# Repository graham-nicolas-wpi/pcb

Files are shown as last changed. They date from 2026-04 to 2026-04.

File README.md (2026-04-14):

# Modular NeoPixel Smart Clock

This repository contains the full clock project for a custom four-digit NeoPixel display board and its long-term two-MCU software stack.

## Permanent Hardware Direction

The custom PCB stays physically unchanged.

- Arduino Leonardo remains on the board as the permanent renderer and board-native hardware controller
- ESP32-WROOM-32E is the external high-level host platform
- ESP32 talks to Leonardo over exposed header pins only
- ESP32 does not directly drive `LED_DIN`
- no PCB redesign and no soldering to hidden custom-board traces are part of the main plan

Preferred UART link:

- ESP32 `GPIO17 TX` -> Leonardo `D0 / RX`
- Leonardo `D1 / TX` -> ESP32 `GPIO16 RX` through a divider or level shifter
- common `GND`

## Repo Layout

- `hardware/pcb/` - KiCad sources, fabrication outputs, schematic exports
- `firmware/arduino/clock_firmware/` - Leonardo renderer runtime using the `ClockRender/1` protocol
- `firmware/arduino/clock_calibration_firmware/` - Leonardo calibration and map-writing firmware using `ClockCal/1`
- `firmware/platformio/esp32_clock/` - ESP32 host platform with web UI, storage, time/network logic, and renderer link control
- `softwear/clockWinder_gui/` - desktop serial tools for Leonardo runtime and calibration workflows
- `docs/leonardo-renderer-esp32-host.md` - canonical coprocessor architecture and serial/render contract

## MCU Responsibilities

### Leonardo

The Leonardo is the stable board appliance:

- renders digits, colon, and decimal to the onboard NeoPixels
- keeps LED mapping and physical calibration authoritative on-board
- reads board buttons and RTC
- exposes a compact serial contract
- supports local fallback clock/timer/stopwatch behavior when no host is attached

### ESP32

The ESP32 is the product brain:

- owns presets, faces, widgets, schedules, and runtime config
- owns NTP, Wi-Fi, storage, browser UI, and future integrations
- compiles rich features into stable renderer commands or `FRAME24` payloads
- treats the Leonardo as a renderer coprocessor instead of replacing it

## Recommended Reading

- Firmware overview: [firmware/README.md](firmware/README.md)
- Leonardo/ESP32 contract: [docs/leonardo-renderer-esp32-host.md](docs/leonardo-renderer-esp32-host.md)
- ESP32 host overview: [firmware/platformio/esp32_clock/README.md](firmware/platformio/esp32_clock/README.md)
- ESP32 host architecture: [firmware/platformio/esp32_clock/ARCHITECTURE.md](firmware/platformio/esp32_clock/ARCHITECTURE.md)
- Desktop GUI notes: [softwear/clockWinder_gui/README.md](softwear/clockWinder_gui/README.md)

## Recommended Workflow

### Bring up the board renderer

1. Flash `firmware/arduino/clock_firmware/` to the Leonardo for normal operation
2. Flash `firmware/arduino/clock_calibration_firmware/` only when you need to remap LEDs
3. Use the desktop GUI for direct Leonardo control or calibration

### Build the long-term product platform

1. Work in `firmware/platformio/esp32_clock/`
2. Connect the ESP32 to the Leonardo over the header UART link
3. Add new features on the ESP32 and emit `ClockRender/1` commands or `FRAME24` frames

## Project Status

- The Leonardo runtime is now being stabilized as a durable renderer/runtime coprocessor.
- The ESP32 project is the long-term expansion surface for nearly all new features.
- The calibration workflow remains Leonardo-owned so physical board mapping stays tied to the actual renderer MCU.

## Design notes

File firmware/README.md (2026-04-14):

# Firmware Overview

This repo now has one permanent two-MCU product architecture:

- Leonardo on the custom PCB as the renderer/runtime coprocessor
- ESP32 as the external host platform over header-accessible UART

## Leonardo Firmware

Folders:

- `arduino/clock_firmware/` - normal renderer runtime using `ClockRender/1`
- `arduino/clock_calibration_firmware/` - calibration and map-writing firmware using `ClockCal/1`

Leonardo responsibilities:

- render the 31 logical targets on the onboard WS2812 chain
- keep physical mapping and calibration board-native
- read the board buttons on `D8`, `D9`, `D10`
- read the DS3231 over I2C
- support stable runtime commands and `FRAME24` rendering
- provide a useful local fallback mode when the ESP32 host is absent

Why runtime and calibration remain split:

- ATmega32U4 flash is tight
- calibration tools are still important, but they do not belong in every everyday runtime build
- keeping calibration separate makes the normal runtime leaner and more durable

## ESP32 Firmware

Folder:

- `platformio/esp32_clock/`

ESP32 responsibilities:

- own saved presets, faces, widgets, and schedules
- own LittleFS config and browser-based UX
- own NTP, network policy, and future integrations
- own command generation toward the Leonardo renderer
- compile high-level host features into stable renderer commands or `FRAME24`

The active ESP32 path no longer assumes direct control of the NeoPixel chain, button wiring, or RTC wiring on the custom board.

## Wiring Contract

Preferred host link:

- ESP32 `GPIO17 TX` -> Leonardo `D0 / RX`
- Leonardo `D1 / TX` -> ESP32 `GPIO16 RX` through level protection
- common `GND`

This architecture avoids PCB redesign and avoids soldering to hidden custom-board traces.

## Desktop App Relationship

The desktop app in `../softwear/clockWinder_gui/` still matters for:

- direct Leonardo runtime control
- calibration using the separate calibration sketch
- bench testing and development

The long-term primary UX for product features is the ESP32 web/API stack.

## What To Use

### Board bring-up

Use Leonardo runtime plus the calibration sketch.

### Product feature work

Use the ESP32 PlatformIO project and treat the Leonardo as a renderer coprocessor.

## Reference

- canonical architecture and protocol: [../docs/leonardo-renderer-esp32-host.md](../docs/leonardo-renderer-esp32-host.md)

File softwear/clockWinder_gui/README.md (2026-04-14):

# ClockWinder Desktop GUI

This is the PySide6 desktop serial tool for the clock project.

Entry point:

- `main.py`

Main package:

- `clock_gui/`

## What it does

The GUI is the desktop-side console for Leonardo runtime and calibration workflows. It supports:

- serial connection with `pyserial`
- `ClockRender/1` runtime hello/status/info
- calibration mode workflow
- mapping table editing
- JSON and header export
- runtime mode control
- brightness and colon brightness control
- color control for clock, timer, and stopwatch targets
- RTC read/set
- timer and stopwatch controls

## Package layout

- `clock_gui/app.py` - Qt application setup and styling
- `clock_gui/protocol.py` - line-based serial command helpers and response parsing
- `clock_gui/model.py` - local mapping and device state models
- `clock_gui/serial_worker.py` - worker-thread serial I/O
- `clock_gui/exports.py` - JSON/header export helpers
- `clock_gui/constants.py` - shared logical IDs, modes, presets, and UI constants
- `clock_gui/widgets/` - reusable widgets
- `clock_gui/windows/main_window.py` - main application window

## Run

Install:

```bash
pip install PySide6 pyserial
```

Launch:

```bash
python main.py
```

## Position In The Project

This app is still very relevant for the Leonardo firmware path.

For the long-term ESP32 path, the plan is different:

- the ESP32 serves its own browser UI
- the ESP32 becomes the main high-level configuration surface
- the Leonardo remains the board-native renderer under that host
- the desktop GUI becomes optional rather than mandatory

That means this app should stay clean and usable, but it does not need to become the long-term primary UX if the ESP32 web path takes over.

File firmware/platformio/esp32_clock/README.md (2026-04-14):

# ESP32 Clock Host

This PlatformIO project is the authoritative high-level host for the clock system. It does not directly drive the custom PCB LED chain.

## Host Role

The ESP32 owns:

- presets, faces, widgets, and future feature composition
- LittleFS-backed configuration and saved state
- Wi-Fi AP/STA behavior
- browser UI and HTTP API
- NTP and other future time sources
- UART communication with the Leonardo renderer

The ESP32 does not own:

- board NeoPixel `DIN`
- board button wiring
- the authoritative LED calibration map
- the board-native RTC wiring path

Those remain Leonardo responsibilities on this board revision.

## Wiring

Preferred renderer link:

- ESP32 `GPIO17 TX` -> Leonardo `D0 / RX`
- Leonardo `D1 / TX` -> ESP32 `GPIO16 RX` through a divider or level shifter
- common `GND`

This is the intended no-PCB-redesign and no-hidden-trace-solder path.

## Project Layout

- `src/main.cpp` - host startup and main loop
- `src/model/ClockConfig.h` - persisted host config model
- `src/storage/SettingsStore.*` - LittleFS JSON persistence
- `src/render/SegmentFrame.*` - stable logical-target frame model
- `src/render/FrameCompiler.*` - compiles presets/faces/widgets into a renderer frame
- `src/host/LeonardoClient.*` - UART client for `ClockRender/1`
- `src/runtime/HostRuntime.*` - host-owned timer, stopwatch, time source, and renderer orchestration
- `src/web/WebUiServer.*` - HTTP API and static file serving
- `data/*` - browser UI assets uploaded to LittleFS

## Renderer Contract

The ESP32 speaks to the Leonardo runtime using `ClockRender/1`.

Important commands include:

- `HELLO ClockRender/1`
- `STATUS?`
- `CONTROL HOST`
- `BTNREPORT 1`
- `RTC READ`
- `RTC SET ...`
- `MAP?`
- `TEST DIGITS|SEGMENTS|ALL`
- `FRAME24 <186 hex chars>`

For the full contract, see [../../../docs/leonardo-renderer-esp32-host.md](../../../docs/leonardo-renderer-esp32-host.md).

## Why This Split Matters

Future product features should usually land in one of these ESP32 layers:

- config model
- web/API surface
- storage and scheduling
- frame compiler
- renderer client/orchestration

The Leonardo should usually stay unchanged unless the stable renderer contract truly needs a new primitive.

## Upload Workflow

1. Install PlatformIO.
2. Build and upload firmware:
   - `pio run -t upload`
3. Upload web assets:
   - `pio run -t uploadfs`
4. Open serial monitor if needed:
   - `pio device monitor`

## First Boot

Default AP:

- SSID: `NeoPixelClock`
- Password: `clockclock`

Open:

- `http://192.168.4.1/`

The web UI edits host config and renderer-link settings, then drives the Leonardo renderer over UART.

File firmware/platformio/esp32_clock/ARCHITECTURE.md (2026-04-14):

# ESP32 Host Architecture

This project is the high-level host half of a two-MCU system.

## Core Idea

The ESP32 owns the evolving product model. The Leonardo owns the stable board-rendering contract.

New product features should normally be added by:

1. extending host config and storage
2. exposing the feature in the web/API layer
3. compiling the result into a stable render frame or compact renderer command

That keeps the Leonardo simple while letting the ESP32 change freely.

## Active Layers

### `src/model`

- `src/model/ClockConfig.h`

This is the host-side persisted product model. The public config now centers on:

- `network`
- `rendererLink`
- `time`
- `runtime`
- `presets`
- `widgets`
- `faces`

Legacy direct-drive hardware and mapping fields remain only for backward config compatibility and are no longer the primary model.

### `src/storage`

- `src/storage/SettingsStore.*`

Persists the host model to LittleFS and performs config import/export.

### `src/render`

- `src/render/SegmentFrame.*`
- `src/render/FrameCompiler.*`

This layer is the stability boundary.

- `SegmentFrame` is the compact logical-target render model
- `FrameCompiler` turns high-level presets, faces, widgets, and runtime state into that frame

Because the ESP32 compiles to this intermediate form, future features can grow without teaching the Leonardo what each feature means.

### `src/host`

- `src/host/LeonardoClient.*`

This is the UART transport/client for `ClockRender/1`.

Responsibilities:

- hello/status/capability probing
- renderer RTC and map reads
- host/local control negotiation
- async event handling
- `FRAME24` transport

### `src/runtime`

- `src/runtime/HostRuntime.*`

This is the orchestration layer for the host platform.

Responsibilities:

- host-owned timer and stopwatch behavior
- time-source priority `NTP -> renderer RTC -> fallback`
- periodic RTC sync back to the renderer
- renderer health polling and control refresh
- button event interpretation
- render scheduling and frame submission

### `src/web`

- `src/web/WebUiServer.*`

Thin HTTP/API layer over the host runtime and config store.

### `data`

- `data/index.html`
- `data/app.css`
- `data/app.js`

The browser UI edits host config and renderer-link settings, shows renderer health, and triggers service actions. It is no longer a mapping editor for the custom board.

## Control Flow

1. ESP32 boots and loads host config from LittleFS.
2. `LeonardoClient` opens UART2 using the configured renderer link.
3. `HostRuntime` discovers the renderer and requests host control.
4. Host state is compiled into a `SegmentFrame`.
5. The frame is sent as `FRAME24`.
6. Leonardo renders the frame using its own logical-to-physical LED map.

## Calibration Boundary

Calibration is intentionally outside the normal ESP32 host flow.

- physical mapping edits belong to the Leonardo calibration sketch
- the ESP32 host may query and export the renderer map
- the ESP32 host should not become the primary writer of board calibration data

## Design Rules

- do not reintroduce direct LED driving on the ESP32 primary path
- keep web actions thin and runtime-driven
- treat `SegmentFrame` and `ClockRender/1` as the stable renderer contract
- keep feature growth on the host side whenever possible

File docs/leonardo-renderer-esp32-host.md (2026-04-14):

# Leonardo Renderer + ESP32 Host

This document is the canonical architecture and protocol contract for the long-term no-PCB-redesign clock stack.

## Hardware Plan

The current custom PCB remains unchanged.

- Leonardo stays permanently installed on the custom board
- Leonardo keeps ownership of the onboard NeoPixel data path, board buttons, and DS3231 path
- ESP32-WROOM-32E is an external host connected through exposed headers only
- the main plan does not involve rewiring `LED_DIN`, soldering to hidden traces, or replacing the Leonardo on this board revision

Recommended UART wiring:

- ESP32 `GPIO17 TX` -> Leonardo `D0 / RX`
- Leonardo `D1 / TX` -> ESP32 `GPIO16 RX` through level protection
- common `GND`
- share power through the accessible headers as appropriate for the build

## Role Split

### Leonardo Renderer

The Leonardo is the board-native rendering appliance.

- renders logical digits, colon, and decimal
- preserves the physical LED map abstraction
- stores and uses the authoritative calibration map
- reads board buttons and RTC
- offers a stable serial control surface
- falls back to local clock/timer/stopwatch behavior when the host is absent or released

### ESP32 Host

The ESP32 is the flexible system brain.

- owns presets, faces, widgets, schedules, storage, and network policy
- owns NTP and other future time sources
- serves the browser UI and HTTP API
- compiles high-level product features into stable renderer commands
- should absorb most future feature growth without requiring Leonardo firmware changes

## Protocol Families

- `ClockRender/1` - Leonardo runtime protocol
- `ClockCal/1` - Leonardo calibration firmware protocol
- `Clock/1` - legacy runtime hello alias kept for migration compatibility

`ClockCal/1` belongs to the calibration sketch only. The normal Leonardo runtime is canonical on `ClockRender/1`.

## Transport

- UART
- `115200` baud by default
- `8N1`
- newline-delimited ASCII commands

## Runtime Control Model

The renderer has two control states:

- `CONTROL LOCAL` - Leonardo standalone behavior is active
- `CONTROL HOST` - ESP32 host is authoritative

In host mode:

- Leonardo buttons no longer mutate renderer state locally
- button presses are surfaced as events when `BTNREPORT 1` is enabled
- the ESP32 translates those events into product behavior

If host traffic stops for roughly 5 seconds, Leonardo returns to local control and emits `EV HOST TIMEOUT`.

## Core Commands

### Session and discovery

- `HELLO`
- `HELLO ClockRender/1`
- `HELLO Clock/1`
- `INFO?`
- `CAPS?`
- `STATUS?`
- `PING`

### Control and board services

- `CONTROL HOST`
- `CONTROL LOCAL`
- `BTNREPORT 0|1`
- `RTC READ`
- `RTC SET yyyy mm dd hh mm ss`
- `MAP?`
- `VALIDATE?`
- `TEST DIGITS`
- `TEST SEGMENTS`
- `TEST ALL`

### Convenience renderer commands

- `MODE CLOCK|CLOCK_SECONDS|TIMER|STOPWATCH|COLOR_DEMO`
- `BRIGHTNESS n`
- `COLONBRIGHTNESS n`
- `COLOR <target> r g b`
- `TIMER SET seconds`
- `TIMER START`
- `TIMER STOP`
- `TIMER RESET`
- `STOPWATCH START`
- `STOPWATCH STOP`
- `STOPWATCH RESET`

These are useful stable controls, but the long-term extensibility lane is the frame contract below.

## Stable Frame Contract

`FRAME24 <payload>`

- payload length: `186` hex characters
- content: `31` logical targets, each encoded as `RRGGBB`
- target order: `LogicalIds.h` order on the Leonardo runtime
- semantic level: logical display targets, not physical pixel indices

That means the ESP32 can invent richer faces, widgets, themes, schedules, and integrations, then reduce them to a `SegmentFrame` without teaching the Leonardo what each new feature means.

## Events

The Leonardo runtime may emit asynchronous events:

- `EV BUTTON BTN1 SHORT`
- `EV BUTTON BTN2 SHORT`
- `EV BUTTON BTN3 SHORT`
- `EV TIMER DONE`
- `EV HOST TIMEOUT`

## Calibration Boundary

Calibration stays Leonardo-owned.

- use `firmware/arduino/clock_calibration_firmware/` to write or repair the LED map
- use `ClockCal/1` for the calibration workflow
- the normal renderer runtime may report mapping and validation state, but it is not the primary map-editing tool

## How To Add Future Features

For most new ideas:

1. add config, storage, UI, and behavior on the ESP32
2. compile that behavior into convenience commands or `FRAME24`
3. keep the Leonardo unchanged unless the stable rendering contract truly needs a new primitive

This keeps the Leonardo durable and lets the ESP32 architecture evolve freely.

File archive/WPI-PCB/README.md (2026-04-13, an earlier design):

# Essentials of PCB Design

[][cc-by-sa]

Project-oriented PCB design course taught at WPI. The course is a evening lecture series where students learn to layout and route an embedded system. Students then receive their boards and assemble them. The class was created by [Daniel Gorbunov](https://github.com/dgorbunov) and [Hubert Liu](https://github.com/124274sashimi) in 2024 and has been run every year since through the [IEEE WPI Student Branch](https://ieee.wpi.edu), which helps fund the class. You can reach us at [gr-pcb@wpi.edu](mailto:gr-pcb@wpi.edu) if you have questions.

### Lectures
| #  | Lecture				 |
| -- |--- 				 |
| 01 | PCB Basics 		 |
| 02 | Project Design |
| 03 | Layout + Routing |
| 04 | Working with KiCad |

### Materials
| Folder 	  | Contents		 |
| -- 	  | --- 			 |
| `datasheets` | Datasheets for major parts  |
| `sample_board`  | Sample board design |
| `slides` | PDFs of slides	 	|
| `starter_board` | Starter template design | 
| `code` | Code examples	 |

### Lecture Recordings

> Note: To access the lecture recordings, you must sign in with a WPI account. This is WPI's policy for Echo360 recordings.

| Year  | Term  | Echo360 |
| ----- | ----- | --- |
| 2024 | A-Term | [Link](https://echo360.org/collection/4c2d5caf-a301-4c32-a2dd-bdd8c8c0b9d9/public) | 
| 2025 | A-Term | [Link](https://echo360.org/collection/bc2acf2f-69f2-4496-9638-cb1b12c30087/public) |
| 2026 | C-Term | [Link](https://echo360.org/collection/0ecf9c61-5003-4061-9b4f-ee87c14e6741/public) |

## Getting Started
Not sure where to get started on your design? You'll need to download and install [KiCad](https://www.kicad.org/download/). You'll also need the [Arduino IDE](https://www.arduino.cc/en/software) to program your board.

### Board
To get started on your own board design, navigate to [starter_board](https://github.com/IEEE-WPI/pcb/tree/main/starter_board) and read the instructions in the `README` file.

### Code
To get started uploading code to your board, navigate to [code](https://github.com/IEEE-WPI/pcb/tree/main/code) and read the instructions in the `README` file.

## License
This work is licensed under a
[Creative Commons Attribution-ShareAlike 4.0 International License][cc-by-sa].

[][cc-by-sa]

[cc-by-sa]: http://creativecommons.org/licenses/by-sa/4.0/
[cc-by-sa-image]: https://licensebuttons.net/l/by-sa/4.0/88x31.png
[cc-by-sa-shield]: https://img.shields.io/badge/License-CC%20BY--SA%204.0-lightgrey.svg

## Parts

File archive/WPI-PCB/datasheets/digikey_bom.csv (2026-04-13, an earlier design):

Country of Origin may be different at time of shipment.
Index | Manufacturer Part Number | Manufacturer Name | Description | Availability | Stock Status | Requested Quantity 1 | Pack Quantity 1 | Pack Type 1 | Digi-Key Part Number 1 | Unit Price 1 | Extended Price 1 | Minimum Order Quantity 1 | Requested Part Number | Lead Weeks | Datasheet | US Import Tariff | Note | Part Status | RoHS Status | Moisture Sensitivity Level (MSL) | ECCN | HTSUS | Country of Origin | Environmental Information | Original Part numbers
1 | ATMEGA32U4-AU | Microchip Technology | IC MCU 8BIT 32KB FLASH 44TQFP | 14,657 | In Stock | 1 | 1 | Tray | ATMEGA32U4-AU-ND | 5.29000 | $5.29 | 1 | atmega32u4-au | 4 | http://ww1.microchip.com/downloads/en/DeviceDoc/Atmel-7766-8-bit-AVR-ATmega16U4-32U4_Summary.pdf | - |  | Active | ROHS3 Compliant | 3 (168 Hours) | EAR99 | 8542.31.0015 | Thailand | https://ww1.microchip.com/downloads/aemDocuments/documents/corporate-responsibilty/environmental/product-regulatory-information/Semiconductor_EnvCoC.pdf|https://ww1.microchip.com/downloads/aemDocuments/documents/corporate-responsibilty/environmental/product-regulatory-information/Microchip_REACH_Statement.pdf | atmega32u4-au
2 | 865080142007 | Würth Elektronik | CAP ALUM 100UF 20% 6.3V SMD | 2,805 | In Stock | 1 | 1 | Cut Tape (CT) | 732-8472-1-ND | 0.20000 | $0.20 | 1 | 732-8472-1-ND | 26 | https://www.we-online.com/components/products/datasheet/865080142007.pdf | May apply on shipments to the U.S. |  | Active | ROHS3 Compliant | 1 (Unlimited) | EAR99 | 8532.22.0020 | China | https://mm.digikey.com/Volume0/opasdata/d220001/medias/docus/744/Certificate_of_Compliance_ROHS.pdf | 732-8472-1-ND
3 | CL21B105KPFNNNE | Samsung Electro-Mechanics | CAP CER 1UF 10V X7R 0805 | 763,033 | In Stock | 2 | 2 | Cut Tape (CT) | 1276-1275-1-ND | 0.10000 | $0.20 | 1 | 1276-1275-1-ND | 22 | http://www.samsungsem.com/kr/support/product-search/mlcc/CL21B105KPFNNNE.jsp | - |  | Active | ROHS3 Compliant | 1 (Unlimited) | EAR99 | 8532.24.0020 | Philippines | https://www.samsungsem.com/files/fileDown.do?key=ed1dfdfa-645e-4252-b707-17f9b1502dd1|https://www.samsungsem.com/global/support/certificate/product-stewardship.do | 1276-1275-1-ND
4 | CL21C220JBANFNC | Samsung Electro-Mechanics | CAP CER 22PF 50V C0G/NP0 0805 | 150,218 | In Stock | 2 | 2 | Cut Tape (CT) | 1276-2606-1-ND | 0.10000 | $0.20 | 1 | 1276-2606-1-ND | 22 | http://www.samsungsem.com/kr/support/product-search/mlcc/CL21C220JBANFNC.jsp | - |  | Active | ROHS3 Compliant | 1 (Unlimited) | EAR99 | 8532.24.0020 | China | https://www.samsungsem.com/files/fileDown.do?key=ed1dfdfa-645e-4252-b707-17f9b1502dd1|https://www.samsungsem.com/global/support/certificate/product-stewardship.do | 1276-2606-1-ND
5 | CL21B104KBCNNNC | Samsung Electro-Mechanics | CAP CER 0.1UF 50V X7R 0805 | 1,739,088 | In Stock | 1 | 1 | Cut Tape (CT) | 1276-1003-1-ND | 0.10000 | $0.10 | 1 | 1276-1003-1-ND | 22 | https://mm.digikey.com/Volume0/opasdata/d220001/medias/docus/609/CL21B104KBCNNN_Spec.pdf | - |  | Active | ROHS3 Compliant | 1 (Unlimited) | EAR99 | 8532.24.0020 | Philippines | https://www.samsungsem.com/files/fileDown.do?key=ed1dfdfa-645e-4252-b707-17f9b1502dd1|https://www.samsungsem.com/global/support/certificate/product-stewardship.do | 1276-1003-1-ND
6 | USB3076-30-A | GCT | MICRO B SKT, BOTTOM-SMT, R/A, 30 | 45,985 | In Stock | 1 | 1 | Cut Tape (CT) | 2073-USB3076-30-ACT-ND | 0.70000 | $0.70 | 1 | 2073-USB3076-30-ACT-ND | 9 | https://gct.co/files/specs/usb3076-spec.pdf | May apply on shipments to the U.S. |  | Active | ROHS3 Compliant | Not Applicable | EAR99 | 8536.69.4040 | China | https://gct.co/files/info/gct_certificate_of_compliance.pdf | 2073-USB3076-30-ACT-ND
7 | LNCD1-16M | NDK America, Inc. | CRYSTAL 16.0000MHZ 8PF SMD | 31,951 | In Stock | 1 | 1 | Cut Tape (CT) | 644-LNCD1-16MCT-ND | 0.58000 | $0.58 | 1 | 644-LNCD1-16MCT-ND | 15 | https://mm.digikey.com/Volume0/opasdata/d220001/medias/docus/973/NX5032GA.pdf | - |  | Active | RoHS Compliant | 1 (Unlimited) | EAR99 | 8541.60.0050 | China |  | 644-LNCD1-16MCT-ND
8 | B1701TW--20P000314U1930 | Harvatek Corporation | LED WHITE 0805 SMD | 31,804 | In Stock | 2 | 2 | Cut Tape (CT) | 3147-B1701TW--20P000314U1930CT-ND | 0.10000 | $0.20 | 1 | 3147-B1701TW--20P000314U1930CT-ND | 8 | https://mm.digikey.com/Volume0/opasdata/d220001/medias/docus/3791/B1701TW--20P000314U1930.pdf | - |  | Active | RoHS Compliant | 2A (4 Weeks) | EAR99 | 8541.41.0000 | Taiwan | https://mm.digikey.com/Volume0/opasdata/d220001/medias/docus/6223/Harvatek%20Corp%20REACH%20235%20Jun%202023%20Statement.pdf | 3147-B1701TW--20P000314U1930CT-ND
9 | PH1-20-UA | Adam Tech | CONN HEADER VERT 20POS 2.54MM | 8,135 | In Stock | 1 | 1 | Bag | 2057-PH1-20-UA-ND | 0.36000 | $0.36 | 1 | 2057-PH1-20-UA-ND | 14 | https://app.adam-tech.com/products/download/data_sheet/201605/ph1-xx-ua-data-sheet.pdf | May apply on shipments to the U.S. |  | Active | ROHS3 Compliant | 1 (Unlimited) | EAR99 | 8536.69.4040 | China |  | 2057-PH1-20-UA-ND
10 | PH2-06-UA | Adam Tech | CONN HEADER VERT 6POS 2.54MM | 11,624 | In Stock | 1 | 1 | Bag | 2057-PH2-06-UA-ND | 0.12000 | $0.12 | 1 | 2057-PH2-06-UA-ND | 14 | https://app.adam-tech.com/products/download/data_sheet/202065/ph2-xx-ua-data-sheet.pdf | May apply on shipments to the U.S. |  | Active | ROHS3 Compliant | 1 (Unlimited) | EAR99 | 8536.69.4040 | China |  | 2057-PH2-06-UA-ND
11 | RC0805FR-07100RL | YAGEO | RES 100 OHM 1% 1/8W 0805 | 169,983 | In Stock | 2 | 2 | Cut Tape (CT) | 311-100CRCT-ND | 0.10000 | $0.20 | 1 | 311-100CRCT-ND | 18 | https://www.yageo.com/upload/media/product/products/datasheet/rchip/PYu-RC_Group_51_RoHS_L_12.pdf | May apply on shipments to the U.S. |  | Active | ROHS3 Compliant | 1 (Unlimited) | EAR99 | 8533.21.0030 | Taiwan | https://www.yageo.com/en/Download/Index/certificates#rchip | 311-100CRCT-ND
12 | RC0805FR-0722RL | YAGEO | RES 22 OHM 1% 1/8W 0805 | 499,387 | In Stock | 2 | 2 | Cut Tape (CT) | 311-22.0CRCT-ND | 0.10000 | $0.20 | 1 | 311-22.0CRCT-ND | 18 | https://www.yageo.com/upload/media/product/products/datasheet/rchip/PYu-RC_Group_51_RoHS_L_12.pdf | May apply on shipments to the U.S. |  | Active | ROHS3 Compliant | 1 (Unlimited) | EAR99 | 8533.21.0030 | Taiwan | https://www.yageo.com/en/Download/Index/certificates#rchip | 311-22.0CRCT-ND
13 | RC0805FR-071KL | YAGEO | RES 1K OHM 1% 1/8W 0805 | 1,825,316 | In Stock | 1 | 1 | Cut Tape (CT) | 311-1.00KCRCT-ND | 0.10000 | $0.10 | 1 | 311-1.00KCRCT-ND | 18 | https://www.yageo.com/upload/media/product/products/datasheet/rchip/PYu-RC_Group_51_RoHS_L_12.pdf | May apply on shipments to the U.S. |  | Active | ROHS3 Compliant | 1 (Unlimited) | EAR99 | 8533.21.0030 | Taiwan | https://www.yageo.com/en/Download/Index/certificates#rchip | 311-1.00KCRCT-ND
14 | RC0805FR-07470RL | YAGEO | RES 470 OHM 1% 1/8W 0805 | 415,773 | In Stock | 1 | 1 | Cut Tape (CT) | 311-470CRCT-ND | 0.10000 | $0.10 | 1 | 311-470CRCT-ND | 18 | https://www.yageo.com/upload/media/product/products/datasheet/rchip/PYu-RC_Group_51_RoHS_L_12.pdf | May apply on shipments to the U.S. |  | Active | ROHS3 Compliant | 1 (Unlimited) | EAR99 | 8533.21.0030 | Taiwan | https://www.yageo.com/en/Download/Index/certificates#rchip | 311-470CRCT-ND
15 | 2686 | Adafruit Industries LLC | ADDRESS LED DISC SERIAL RGB 10PK | 185 | In Stock | 1 | 1 | Bulk | 1528-1541-ND | 4.95000 | $4.95 | 1 | 1528-1541-ND | 6 | https://cdn-shop.adafruit.com/product-files/2686/SK6812MINI_REV.01-1-2.pdf | - |  | Active | ROHS3 Compliant | 5A (24 Hours) | EAR99 | 8541.41.0000 | China |  | 1528-1541-ND

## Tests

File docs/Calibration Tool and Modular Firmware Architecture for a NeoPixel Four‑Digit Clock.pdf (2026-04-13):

# Calibration Tool and Modular Firmware Architecture for a NeoPixel Four‑Digit Clock

# System context and constraints

Your hardware target (Arduino Leonardo / ATmega32U4, 31 WS2812 LEDs on D5, 3 active‑low buttons on D8/D9/D10, future DS3231 RTC) is very workable, but the constraints are real and should shape both the calibration workflow and the long‑term firmware architecture.

The ATmega32U4 class devices used by the Leonardo provide 32 KB flash (with 4 KB used by the bootloader), 2.5 KB SRAM, and 1 KB EEPROM. This is enough for a clean modular clock firmware with a NeoPixel display abstraction, RTC support, and a few sensors, but it will not comfortably absorb “smart” features like full Wi‑Fi stacks, rich networking protocols, or large JSON handling without careful scope control.

Driving WS2812/NeoPixel LEDs has two key implications. First, the core timing is strict enough that libraries typically disable interrupts while shifting out pixel data. Second, that interrupt suppression can slightly distort Arduino timing functions: Adafruit documents that interrupts are “temporarily disabled” and that
millis() | / | micros() | “will lose small intervals of time” during | show() | , roughly ~30 µs per RGB pixel.
For 31 RGB pixels, that is about 31 × 30 µs ≈ 0.93 ms of interrupts‑off time per refresh (plus the
WS2812 reset/latch low interval); the practical takeaway is that frequent full‑strip updates are fine for a clock UI, but you still want a cooperative main loop and you should avoid designs that require high‑precision interrupt timing during pixel refresh.

Memory use is favorable at your LED count: Adafruit notes that each NeoPixel consumes about 3 bytes of RAM for RGB buffering, so 31 pixels cost ~93 bytes for the pixel buffer. Your larger RAM pressures will come from UI state, settings, and any parsing/serialization you do, not the pixels.

On the Leonardo specifically, serial communication and tool design should respect two USB‑native

### behaviors:

For USB CDC serial ports (e.g., | Serial | on the Leonardo), | Serial.begin() | “is irrelevant” (baud is
ignored).
Reset-to-bootloader behavior is triggered by opening the CDC port at 1200 baud and closing it (a common “Caterina” bootloader convention).
Your calibration GUI should never do “1200‑baud touch” unless you explicitly want to force a reset.

Finally, your preferred RTC add‑on is a strong choice: the DS3231 is an I2C RTC with an integrated temperature‑compensated oscillator; the datasheet calls out ±2 minutes/year accuracy across −40°C to +85°C, provides alarms, and exposes a 32 kHz output pin.

1 (https://store-usa.arduino.cc/products/arduino-leonardo-with-headers)

2

3

4 (https://adafruit.github.io/Adafruit_NeoPixel/html/class_adafruit___neo_pixel.html)

5 (https://learn.adafruit.com/adafruit-neopixel-uberguide/arduino-library-use?utm_source=chatgpt.com)

•

6 (https://www.arduino.cc/en/Serial/Begin?utm_source=chatgpt.com)
•

7 (https://github.com/sudar/Arduino-Makefile/issues/30?utm_source=chatgpt.com)

8 (https://www.analog.com/media/en/technical-documentation/data-sheets/ds3231.pdf)

# Calibration workflow architecture

The calibration problem is fundamentally a mapping problem: physical LED indices 0…30 are in an unknown
physical order, and you need to assign each to a logical “display position” such as | D2_F | or | COLON_TOP | .
Because the mapping is unique to the physical build, the workflow should be fast, obvious, and recoverable.

### A practical, maintainable architecture is a three‑layer calibration system:

### Device firmware (calibration service)

Implements a Calibration Mode in which exactly one physical LED is highlighted at a time.
Accepts commands over USB serial to: move to next/previous physical LED, assign the current LED to a logical position, mark unused, save/load mapping, and run test patterns.
Stores mapping locally in EEPROM (so it survives power cycles), and can export the mapping over serial for the GUI to save as JSON and/or generate firmware code.

### Desktop calibration tool (GUI)

Opens the serial connection, queries device capability ( | NUM_PIXELS | , firmware version, supported
protocol version).
Provides a “pick logical position” UI; when you press “Assign,” it sends an assignment command and automatically advances the device highlight to the next pixel.

### Artifacts (exports)

A human‑inspectable JSON mapping (versioned schema).
A generated Arduino header ( | .h | ) you can compile into firmware builds (or use in unit tests/
simulations).
Optionally, a binary blob that matches the EEPROM layout (handy for factory programming or mass‑production flashing).

The biggest design decision is how the rest of your firmware will use the mapping. You want the higher‑level clock code to never care about physical index order. The most robust approach is to

### standardize on a logical ID enumeration and build two mapping views:

physToLogical[NUM_PIXELS] | (used by calibration and validation)
logicalToPhys[LOGICAL_COUNT] | (used by rendering; fast lookups)
Because you have exactly 4×7 + 2 + 1 = 31 logical positions, you can treat | LOGICAL_COUNT ==
NUM_PIXELS | for your current hardware, while still supporting | UNUSED | for future revisions or partial
builds.

# Serial protocol between device and GUI

### A calibration protocol should be:

Line-oriented, human debuggable (Serial Monitor friendly).

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
Idempotent where possible (re-sending doesn’t corrupt state).
Versioned so you can evolve it without breaking older tools.
Simple to implement on an 8‑bit MCU (avoid heavy parsing).
A good “sweet spot” is a newline‑terminated ASCII protocol with | CMD arg1 arg2 ... | requests and
OK ... | / | ERR code message | responses.

## Protocol overview

### Transport

USB CDC serial ( | Serial | on Leonardo). Baud rate is ignored by the device side for USB CDC, but you
can still standardize on “115200” for tooling convention.
Line endings: | \n | recommended; accept | \r\n | too.

### Handshake

Host sends: | HELLO ClockCal/1
Device responds: | OK HELLO ClockCal/1 FW=<semver> PIXELS=31 LOGICAL=31

### Core commands

INFO? | → metadata (board, pin, pixels, protocol version)
MODE CAL | / | MODE RUN
CUR? | → current physical index
SET <i> | → set highlighted physical LED index | i | (0..30)
NEXT | / | PREV | → step current physical index (wrap optional)
ASSIGN <logicalId> | → assign current physical LED to logical ID
ASSIGN_NAME <name> | → optional convenience if you want names on-device
UNASSIGN <i> | or | UNASSIGN_CUR
MAP? | → dump | physToLogical | mapping
VALIDATE? | → device-side validation summary
SAVE | / | LOAD | → persist/restore mapping (EEPROM)
TEST DIGITS | / | TEST SEGMENTS | / | TEST ALL | → mapping verification patterns

### Responses

Success: | OK <cmd> ...
Error: | ERR <numericCode> <shortMessage>

## Why not JSON on the wire?

NDJSON (newline-delimited JSON) is a fine protocol in general, but on ATmega32U4 the “cost” is not the bytes; it’s the complexity of parsing (and the temptation to add features that require more parsing). You can still export JSON from the GUI, which is the safer place to do it. If later you move to ESP32, you can layer in NDJSON without reworking the rest of the architecture. (If you do want a browser-based GUI, Web Serial

### makes NDJSON attractive; see below.)

•
•
•

•

9 (https://www.arduino.cc/en/Serial/Begin?utm_source=chatgpt.com)
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
## USB reset gotcha

Because Leonardo-class bootloaders can use the “open at 1200 baud then close” pattern to trigger reset into the bootloader, avoid doing that in your calibration GUI unless it’s an intentional “Reset Device” button.

# Desktop GUI framework and data model

## Recommended desktop framework

### A practical, simple desktop stack for this kind of calibration tool is:

### Python + PySide6 (Qt for Python) for UI pySerial for serial I/O JSON + header generation in Python

This choice is attractive because PySide6 is the official Qt for Python binding (i.e., you get “real Qt” widgets and layouts), and pySerial provides cross-platform serial backends for Windows/macOS/Linux.

If you want a “no install” alternative later, a web UI using the Web Serial API is viable on Chromium-based browsers (and documented by MDN/Chrome). I would still start with PySide6 for simplicity and fewer browser-permission constraints.

## Data model for storing the mapping

### Define a versioned schema that cleanly supports:

### the mapping itself device metadata (pin, LED type) orientation assumptions (which digit is “D1”)

### A pragmatic JSON format is an array of logical names indexed by physical LED index:

{
"schema": "neopixel-clock-map/v1", "num_pixels": 31,
"pixel_pin": 5,
"color_order": "GRB",
"phys_to_logical": [
"D1_A", "D1_B", "...", "DECIMAL" ],
"notes": {
"digit_order": "D1 D2 : D3 D4" }
}

7 (https://github.com/sudar/Arduino-Makefile/issues/30?utm_source=chatgpt.com)

•
•
•

10 (https://doc.qt.io/qtforpython-6/?utm_source=chatgpt.com)

11 (https://developer.mozilla.org/en-US/docs/Web/API/Web_Serial_API?utm_source=chatgpt.com)

•
•
•

### Why array-of-strings?

Fast to validate.
Easy to diff in git.
Easy to load even in constrained firmware (if you ever choose to load JSON over serial on larger MCUs).

Inside firmware, you’ll usually compile this down to numeric IDs.

## Export formats

### Arduino header (.h)

### Contains:

enum LogicalId : uint8_t
constexpr uint8_t kPhysToLogical[31]
constexpr uint8_t kLogicalToPhys[31] | (or | int8_t | with | -1 | if unassigned)

### JSON

The schema above, with a version tag.

### Optionally:

A binary blob matching your EEPROM layout (for factory programming).

## Suggested GUI UX flow

### A calibration UX that stays fast and avoids mistakes:

### Connect

User selects COM port (or “Auto-detect”).
GUI sends | HELLO | , shows device metadata and protocol version.

### Walk

Device highlights physical LED 0.
GUI shows: | Current physical LED: 0 | and the currently assigned logical target (if any).

### Assign

### User chooses a logical target from a structured picker: Digit tabs: D1, D2, D3, D4 Segment buttons: A–G shown in a 7-seg diagram layout

Special buttons: | COLON_TOP | , | COLON_BOTTOM | , | DECIMAL | , | UNUSED
When user clicks a target, GUI: 1) sends | ASSIGN <logicalId> | 2) waits for | OK | 3) automatically
sends | NEXT | 4) updates the on-screen mapping table

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
### Validate continuously

GUI warns immediately if a logical target is already used.
GUI shows a completion meter: “28/31 segments assigned; colon: ok; decimal: missing” (or similar).

### Save

GUI sends | VALIDATE? | and requires “no duplicates” before enabling “Save to device.”
GUI sends | SAVE | .

### GUI saves JSON locally and offers “Export header.”

### Verify

GUI offers one-click tests: | TEST SEGMENTS | , | TEST DIGITS | , | TEST ALL | .

## Desktop GUI sample code skeleton

Below is a compact example showing the key architecture: a serial worker thread, a mapping model, validation, and export generation. It’s intentionally not a full polished UI, but it is a solid starting point.

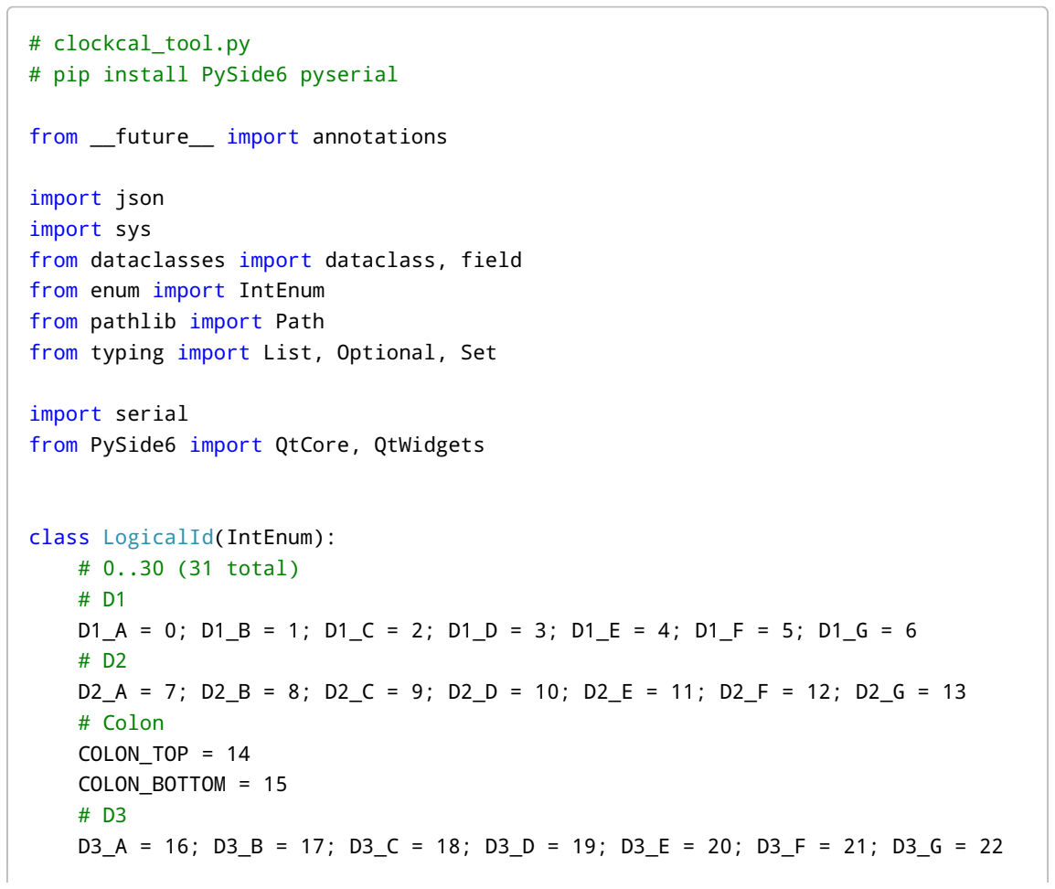
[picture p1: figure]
# clockcal_tool.py # pip install PySide6 pyserial; from __future__ import annotations; import json import sys from dataclasses import dataclass, field from enum import IntEnum from pathlib import Path from typing import List, Optional, Set; import serial from PySide6 import QtCore, QtWidgets; class LogicalId(IntEnum): # 0..30 (31 total) # D1; # Colon COLON_TOP = 14 COLON_BOTTOM = 15 # D3

D1_A = 0; D1_B = 1; D1_C = 2; D1_D = 3; D1_E = 4; D1_F = 5; D1_G = 6

D2_A = 7; D2_B = 8; D2_C = 9; D2_D = 10; D2_E = 11; D2_F = 12; D2_G = 13

D3_A = 16; D3_B = 17; D3_C = 18; D3_D = 19; D3_E = 20; D3_F = 21; D3_G = 22

•
•

•
•
•

•

# D4

D4_A = 23; D4_B = 24; D4_C = 25; D4_D = 26; D4_E = 27; D4_F = 28; D4_G = 29 # Decimal point
DECIMAL = 30

@staticmethod
def from_name(name: str) -> "LogicalId": return LogicalId[name]

LOG_UNUSED = 255

@dataclass
class MappingModel:
num_pixels: int = 31
pixel_pin: int = 5
phys_to_logical: List[int] = field(default_factory=lambda: [LOG_UNUSED] * 31)

def assign(self, phys: int, logical: int) -> None: self._check_phys(phys)
self.phys_to_logical[phys] = logical

def _check_phys(self, phys: int) -> None: if not (0 <= phys < self.num_pixels):
raise ValueError(f"phys index out of range: {phys}")

def used_logicals(self) -> Set[int]:
return {v for v in self.phys_to_logical if v != LOG_UNUSED}

def validate(self) -> List[str]:
errors: List[str] = []
used = [v for v in self.phys_to_logical if v != LOG_UNUSED] if len(used) != len(set(used)):
errors.append("Duplicate logical assignment detected.") expected = set(int(x) for x in LogicalId)
missing = sorted(expected - self.used_logicals())
if missing:
# You can decide whether missing is an error or a warning errors.append(f"Unassigned logical positions: {len(missing)}") return errors

def to_json_obj(self) -> dict: names = []
for v in self.phys_to_logical: if v == LOG_UNUSED:
names.append("UNUSED")

else:
names.append(LogicalId(v).name) return {
"schema": "neopixel-clock-map/v1", "num_pixels": self.num_pixels, "pixel_pin": self.pixel_pin, "color_order": "GRB",
"phys_to_logical": names,
"notes": {"digit_order": "D1 D2 : D3 D4"}, }

def export_header(self) -> str:
# Generate both arrays

logical_count = len(list(LogicalId))
logical_to_phys = [255] * logical_count
for phys, logical in enumerate(self.phys_to_logical):
if logical != LOG_UNUSED and logical < logical_count: logical_to_phys[logical] = phys

def arr(vals: List[int]) -> str:
return "{ " + ", ".join(str(v) for v in vals) + " }"

enum_lines = [f" {lid.name} = {int(lid)}," for lid in LogicalId] return "\n".join([
"#pragma once",
"#include <stdint.h>",
"",
"constexpr uint8_t kNumPixels = 31;", "constexpr uint8_t kPixelPin = 5;", "",
"enum LogicalId : uint8_t {", *enum_lines,
" LOGICAL_COUNT = 31,",
" LOG_UNUSED = 255",
"};",
"",
f"constexpr uint8_t kPhysToLogical[kNumPixels] = {arr(self.phys_to_logical)};", f"constexpr uint8_t kLogicalToPhys[LOGICAL_COUNT] = {arr(logical_to_phys)};",
"",
])

class SerialWorker(QtCore.QObject): line_rx = QtCore.Signal(str) connected = QtCore.Signal(bool, str)

def __init__(self) -> None: super().__init__()
self._ser: Optional[serial.Serial] = None self._timer = QtCore.QTimer() self._timer.setInterval(10) self._timer.timeout.connect(self._poll)

def connect_port(self, port: str) -> None: try:
self._ser = serial.Serial(port=port, baudrate=115200, timeout=0) self._timer.start()
self.connected.emit(True, f"Connected: {port}")
except Exception as e:
self.connected.emit(False, f"Connect failed: {e}")

def send(self, line: str) -> None:
if not self._ser:
return
data = (line.strip() + "\n").encode("utf-8") self._ser.write(data)

def _poll(self) -> None:
if not self._ser:
return
try:
while self._ser.in_waiting:
raw = self._ser.readline() # newline-terminated protocol
if not raw:
break
self.line_rx.emit(raw.decode("utf-8", errors="replace").strip()) except Exception as e:
self.connected.emit(False, f"Serial error: {e}") self._timer.stop()
self._ser = None

class MainWindow(QtWidgets.QWidget): def __init__(self) -> None: super().__init__()
self.setWindowTitle("ClockCal")

self.model = MappingModel() self.cur_phys = 0

# UI

self.port_box = QtWidgets.QLineEdit() self.port_box.setPlaceholderText("COM3 or /dev/ttyACM0")

self.connect_btn = QtWidgets.QPushButton("Connect") self.hello_btn = QtWidgets.QPushButton("HELLO") self.prev_btn = QtWidgets.QPushButton("Prev") self.next_btn = QtWidgets.QPushButton("Next")

self.logical_box = QtWidgets.QComboBox() self.logical_box.addItem("UNUSED", LOG_UNUSED) for lid in LogicalId:
self.logical_box.addItem(lid.name, int(lid))

self.assign_btn = QtWidgets.QPushButton("Assign + Next")

self.log = QtWidgets.QPlainTextEdit() self.log.setReadOnly(True)

self.save_json_btn = QtWidgets.QPushButton("Save JSON") self.save_h_btn = QtWidgets.QPushButton("Export .h")

layout = QtWidgets.QVBoxLayout(self)
top = QtWidgets.QHBoxLayout() top.addWidget(self.port_box) top.addWidget(self.connect_btn) layout.addLayout(top)

row = QtWidgets.QHBoxLayout() row.addWidget(self.hello_btn) row.addWidget(self.prev_btn) row.addWidget(self.next_btn) layout.addLayout(row)

row2 = QtWidgets.QHBoxLayout() row2.addWidget(self.logical_box) row2.addWidget(self.assign_btn) layout.addLayout(row2)

row3 = QtWidgets.QHBoxLayout() row3.addWidget(self.save_json_btn) row3.addWidget(self.save_h_btn) layout.addLayout(row3)

layout.addWidget(self.log)

# Serial worker thread

self.worker = SerialWorker() self.thread = QtCore.QThread() self.worker.moveToThread(self.thread) self.thread.start()

# Signals

self.connect_btn.clicked.connect(self._connect) self.hello_btn.clicked.connect(lambda: self.worker.send("HELLO ClockCal/ 1"))
self.prev_btn.clicked.connect(lambda: self.worker.send("PREV")) self.next_btn.clicked.connect(lambda: self.worker.send("NEXT")) self.assign_btn.clicked.connect(self._assign_next) self.save_json_btn.clicked.connect(self._save_json) self.save_h_btn.clicked.connect(self._save_h)

self.worker.connected.connect(self._on_conn) self.worker.line_rx.connect(self._on_line)

def _connect(self) -> None:
port = self.port_box.text().strip() QtCore.QMetaObject.invokeMethod(
self.worker, "connect_port", QtCore.Qt.QueuedConnection, QtCore.Q_ARG(str, port)
)

def _on_conn(self, ok: bool, msg: str) -> None: self.log.appendPlainText(msg)

def _on_line(self, line: str) -> None: self.log.appendPlainText("<< " + line) # Very small parser example:
if line.startswith("CUR "): self.cur_phys = int(line.split()[1])

if line.startswith("MAP "):
# MAP <comma-separated 31 ints>

payload = line[4:].strip()
parts = [int(x) for x in payload.split(",")] if len(parts) == self.model.num_pixels: self.model.phys_to_logical = parts

def _assign_next(self) -> None:
logical = int(self.logical_box.currentData())
# GUI-side duplicate prevention (hard error)

if logical != LOG_UNUSED and logical in self.model.used_logicals(): self.log.appendPlainText("!! Logical already used; choose another.") return
self.model.assign(self.cur_phys, logical)
self.worker.send(f"ASSIGN {logical}")
self.worker.send("NEXT")

def _save_json(self) -> None:
path, _ = QtWidgets.QFileDialog.getSaveFileName(self, "Save JSON",

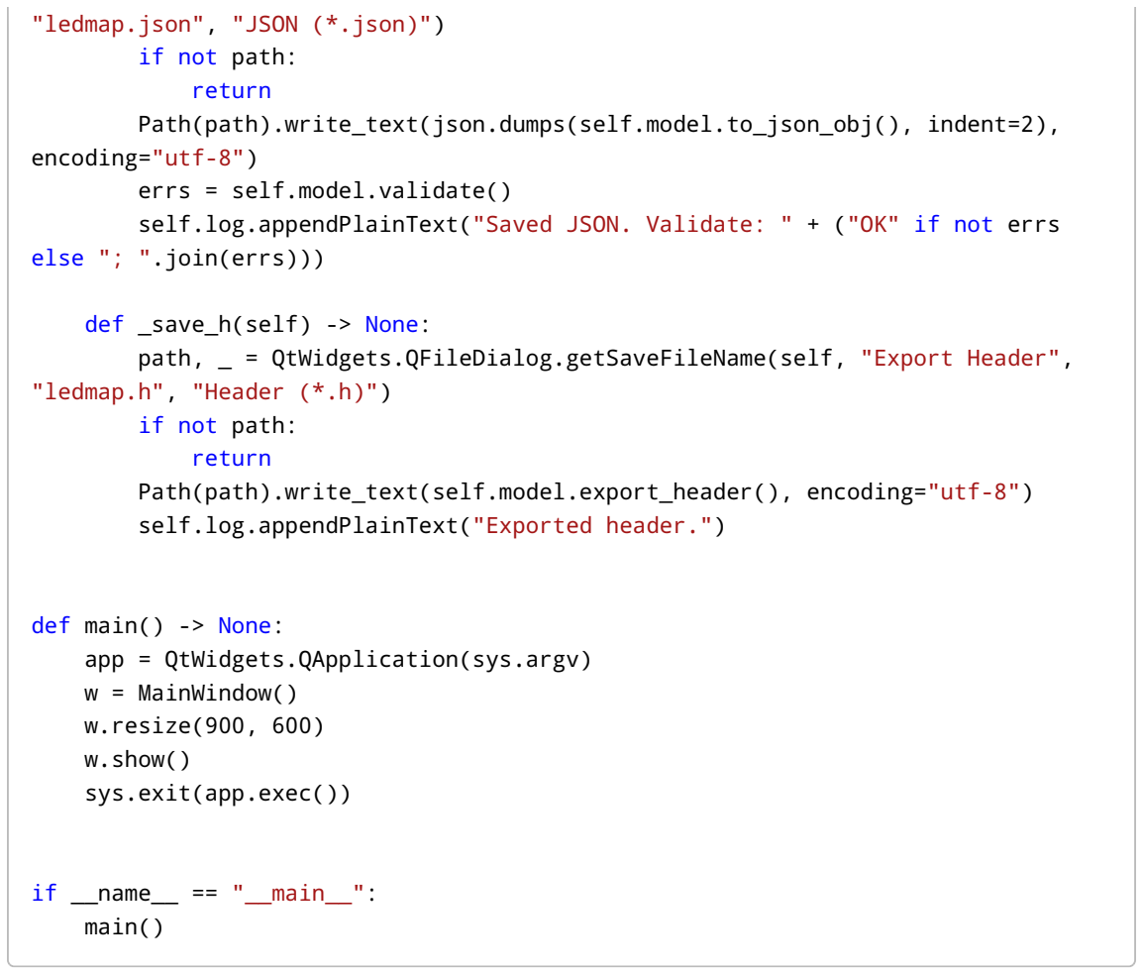
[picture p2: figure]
"ledmap.json", "JSON (*.json)") if not path: return Path(path).write_text(json.dumps(self.model.to_json_obj(), indent=2), encoding="utf-8") errs = self.model.validate(); else "; ".join(errs))); def _save_h(self) -> None:; "ledmap.h", "Header (*.h)") if not path: return Path(path).write_text(self.model.export_header(), encoding="utf-8") self.log.appendPlainText("Exported header."); def main() -> None: app = QtWidgets.QApplication(sys.argv) w = MainWindow() w.resize(900, 600) w.show() sys.exit(app.exec()); if __name__ == "__main__": main()

self.log.appendPlainText("Saved JSON. Validate: " + ("OK" if not errs

path, _ = QtWidgets.QFileDialog.getSaveFileName(self, "Export Header",

This skeleton already demonstrates the critical anti-footgun behavior: it blocks assigning the same logical segment twice, and it keeps a local mapping model that can be exported to JSON/header even if the device resets mid-calibration.

# Firmware architecture for a long‑term, modular clock

You asked explicitly for “not a one-off sketch.” The best way to stay maintainable on Arduino-class MCUs is to design around layers and stable interfaces, while keeping allocation and runtime complexity low.

## Recommended firmware architecture

### A durable structure on ATmega32U4 looks like this:

### Hardware Abstraction Layer (HAL)

Buttons | (debounce, events)
PixelDriver | (NeoPixel buffer + | show() | )

•
•

RtcDriver | (DS3231 via I2C)
Sensors | (optional; abstract early even if not populated)

### Core services

TimeService | (current time source; either “software time” or RTC-backed)
SettingsStore | (EEPROM read/write, versioning, CRC)
DisplayService | (logical display drawing; owns the mapping)
CommsService | (serial protocol, calibration mode messages)
Scheduler | (cooperative tick scheduling)

### App/UI layer

ModeStateMachine | (Clock / Timer / Stopwatch / Weather / Settings / Profile select)
WatchFace | interface (plugin-like renderers)
ProfileManager | (face selection, brightness, color themes, 12/24h, etc.)

## Display abstraction layer (critical)

This is the heart of your maintainability goals: everything above the display layer should talk in terms of logical segments and digits, not physical LED indices.

### Concretely:

LedMap
Owns | physToLogical | and | logicalToPhys | .

LogicalDisplay

### API like:

setSegment(digitIndex, segment, color)

setColon(topOn, bottomOn, color)
setDecimal(on, color)
renderDigit(digitIndex, value, color) | (using a digit->segment mask table)
clear() | / | show()

This lets you replace the physical display (or move to ESP32) without rewriting watch faces or state machines.

## Suggested file/module layout

This layout works in Arduino IDE (multiple | .h/.cpp | files) and ports cleanly to PlatformIO later:

src/

### main.ino (thin wiring only)

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
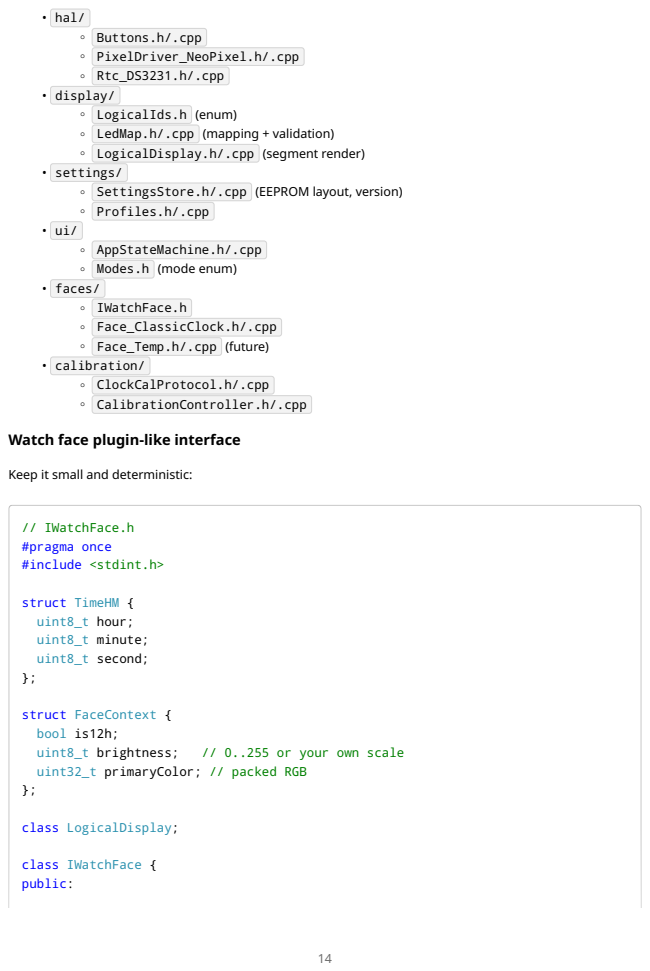
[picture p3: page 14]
hal/; Buttons.h/.cpp PixelDriver_NeoPixel.h/.cpp Rtc_DS3231.h/.cpp display/; LogicalIds.h; (enum); LedMap.h/.cpp; (mapping + validation); LogicalDisplay.h/.cpp; (segment render); settings/; SettingsStore.h/.cpp; (EEPROM layout, version); Profiles.h/.cpp; AppStateMachine.h/.cpp; Modes.h; (mode enum); faces/ IWatchFace.h Face_ClassicClock.h/.cpp; Face_Temp.h/.cpp; (future); calibration/ ClockCalProtocol.h/.cpp CalibrationController.h/.cpp; // IWatchFace.h #pragma once #include <stdint.h>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

Watch face plugin-like interface

Keep it small and deterministic:

struct FaceContext {
bool is12h;
uint32_t primaryColor; // packed RGB

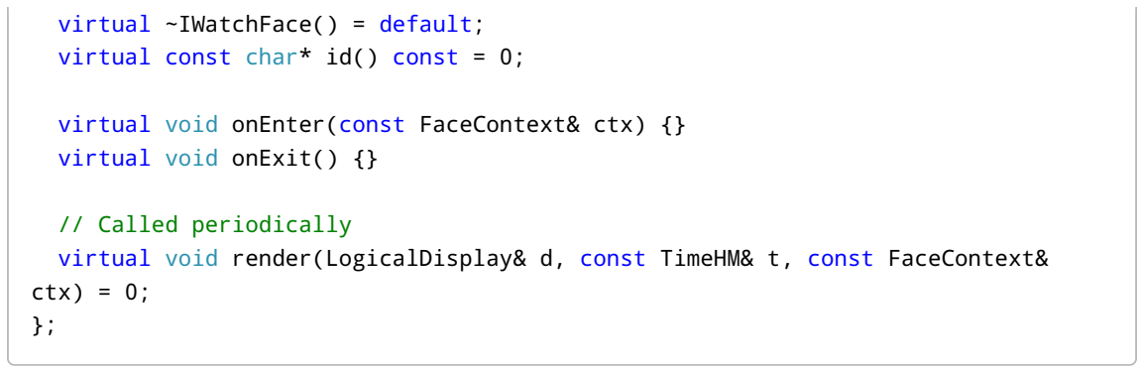
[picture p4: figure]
virtual ~IWatchFace() = default; virtual const char* id() const = 0;; virtual void onExit() {}; // Called periodically; ctx) = 0; };

virtual void onEnter(const FaceContext& ctx) {}

virtual void render(LogicalDisplay& d, const TimeHM& t, const FaceContext&

This interface is “static polymorphism friendly” too: on AVR you can avoid heap allocation by instantiating faces as global singletons and storing pointers in a table.

## State machine for modes/screens

### Use a strict event-driven state machine with debounced button events:

Events: | BTN1_SHORT | , | BTN1_LONG | , | BTN2_SHORT | , …, | TICK_10MS | , | TICK_1S | , | RTC_SYNC | , etc.
States: | Clock | , | Timer | , | Stopwatch | , | Weather | , | Settings | , | ProfileSelect | , | Calibration

### (possibly hidden behind a boot-time chord)

NeoPixel refresh should be controlled by the display service (e.g., “render at 30 fps max, but only if dirty”).

## Hardware abstraction plan

Buttons: poll at 5–10 ms intervals; generate edge events.
RTC: DS3231 over I2C; it is an I2C RTC with registers accessible over bus, and the chip itself provides accurate timekeeping via TCXO.
Display: treat as an output device driven by | LogicalDisplay | , backed by the mapping.
Future sensors: create | ISensorProvider | interface early, even if it returns “not available.”
Wi‑Fi: keep behind an interface and compile-flag it out on AVR.

## ATmega32U4 longevity vs migrating to ESP32

Recommendation: stay on ATmega32U4 for staged development through “good clock + RTC + calibration + basic timers + a couple sensors,” and plan an ESP32 migration once Wi‑Fi, richer UIs, or heavy configuration workflows become core requirements.
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

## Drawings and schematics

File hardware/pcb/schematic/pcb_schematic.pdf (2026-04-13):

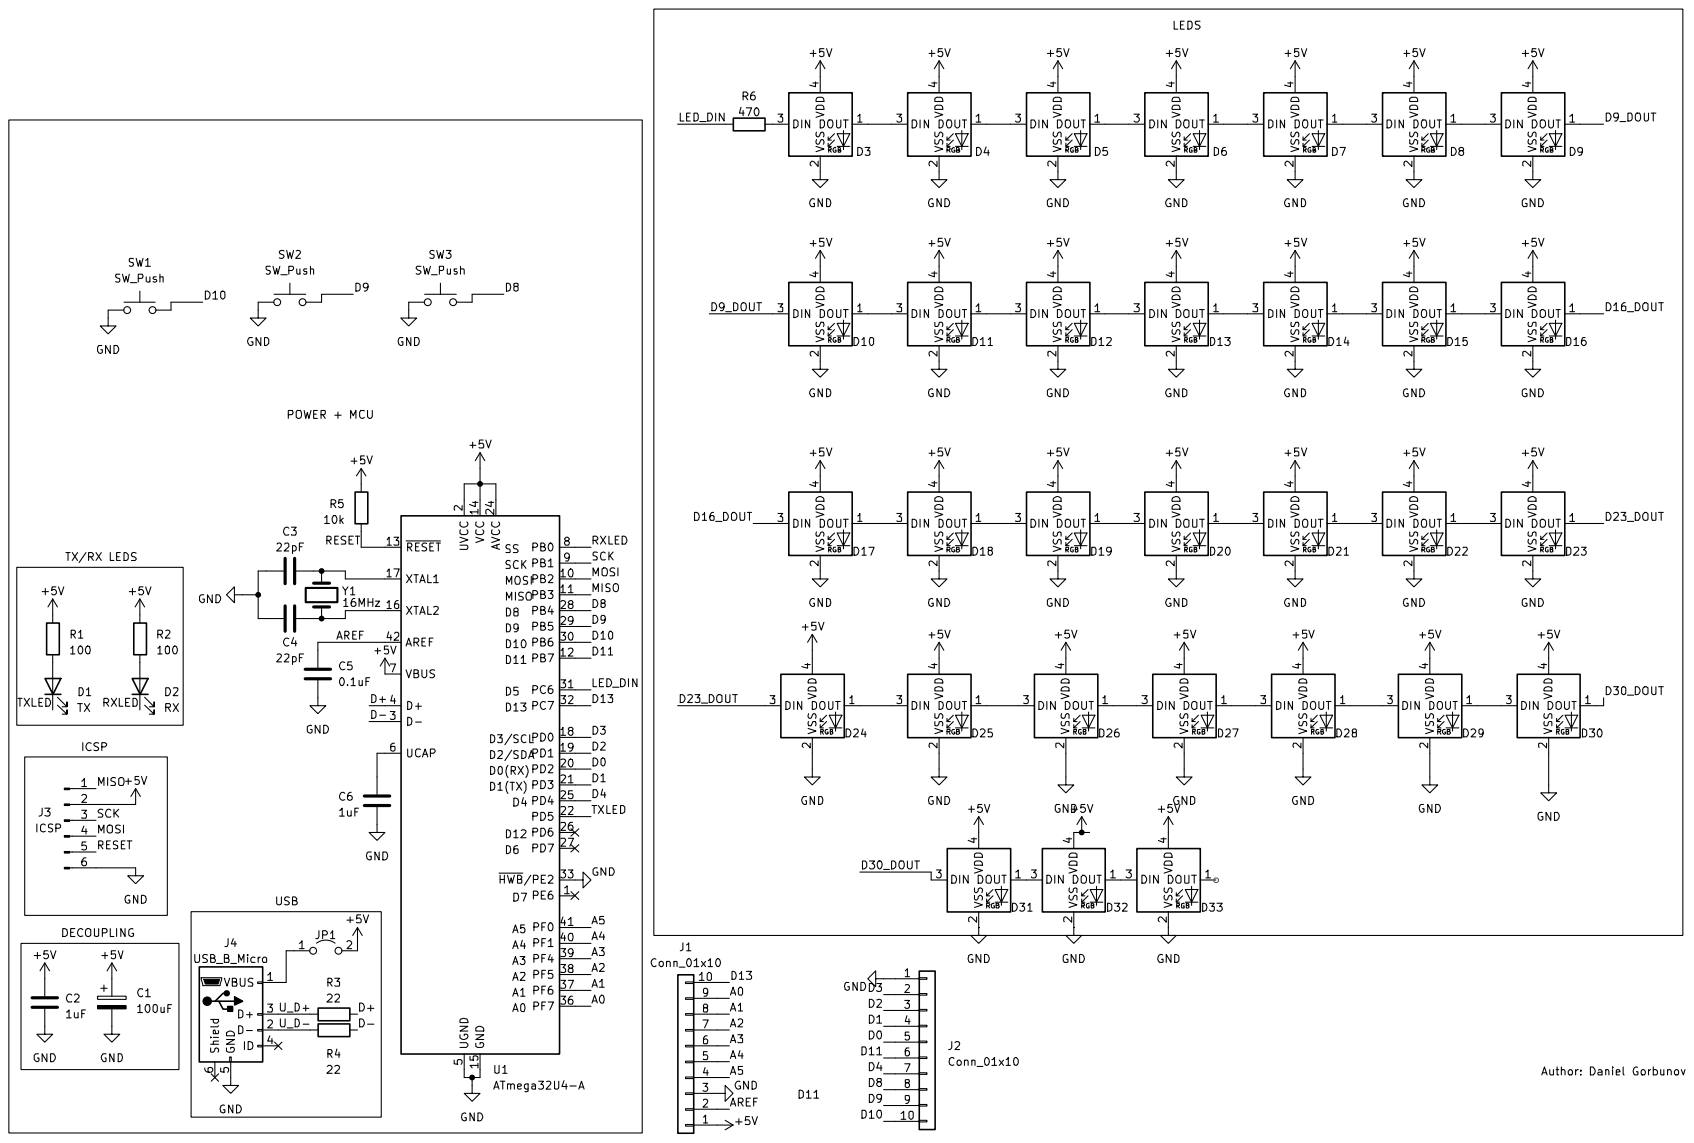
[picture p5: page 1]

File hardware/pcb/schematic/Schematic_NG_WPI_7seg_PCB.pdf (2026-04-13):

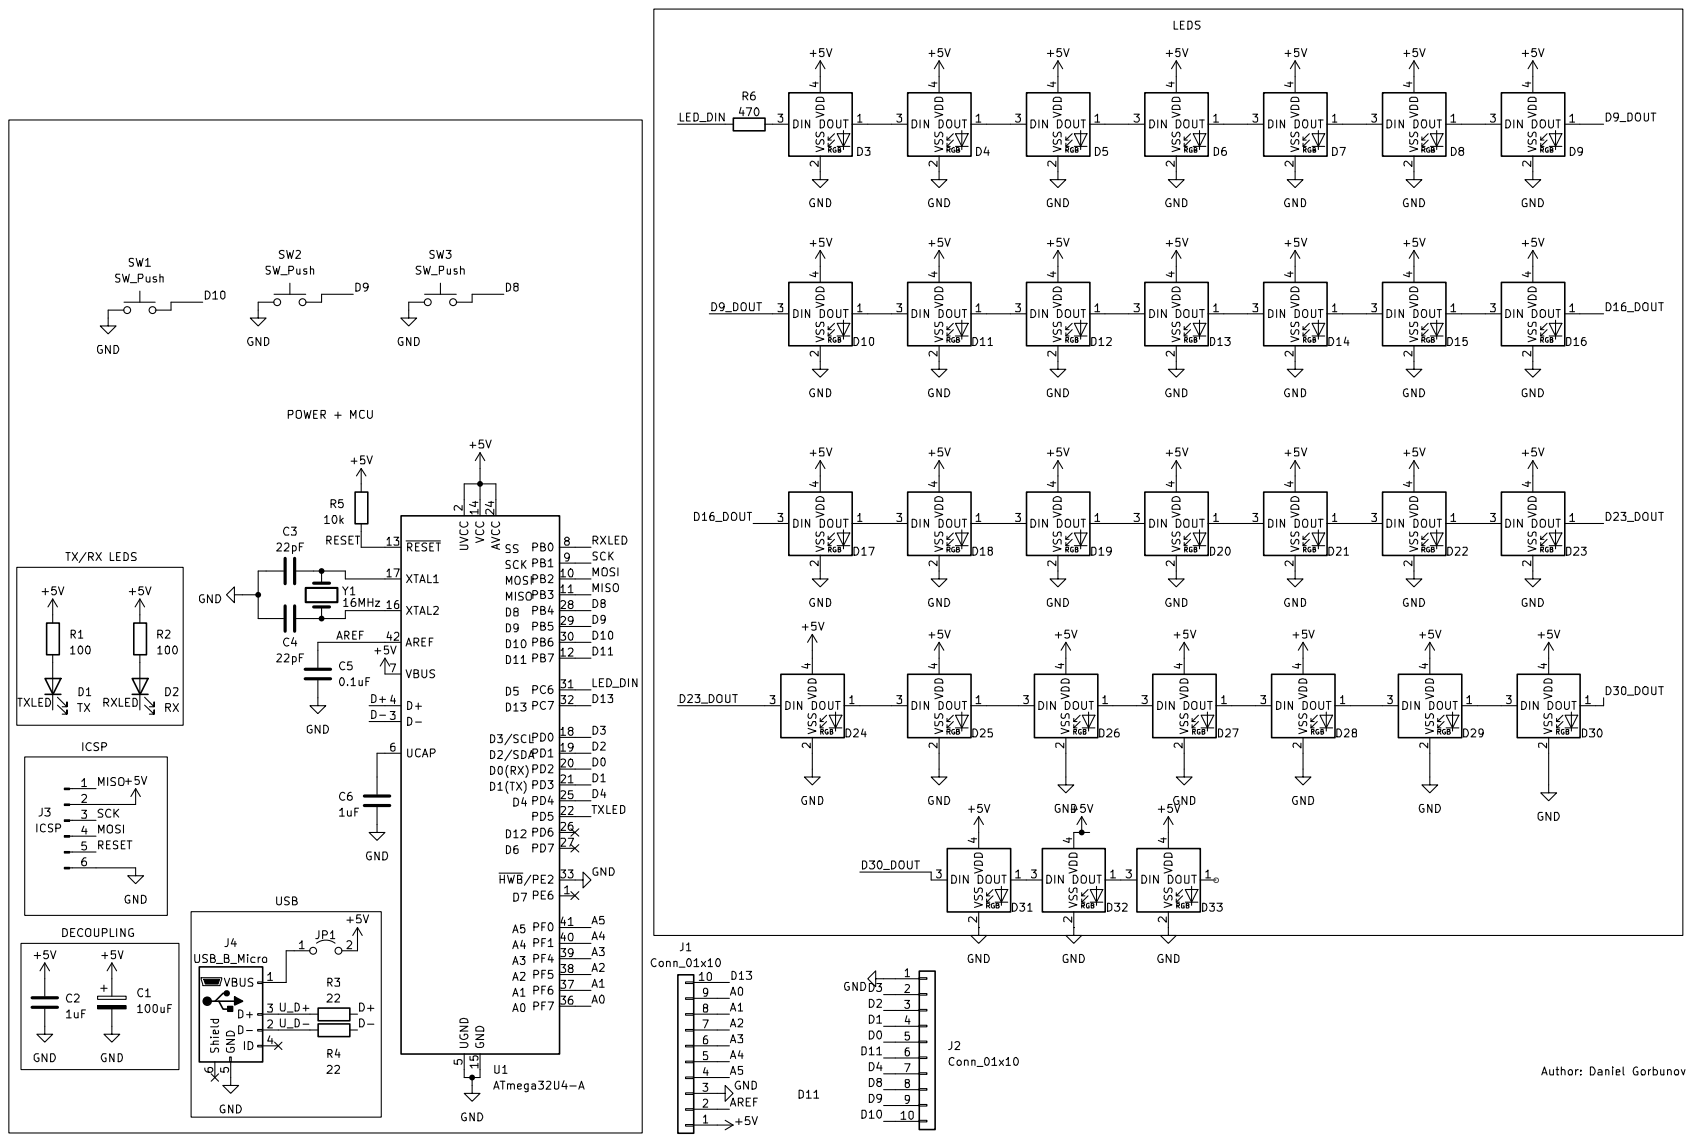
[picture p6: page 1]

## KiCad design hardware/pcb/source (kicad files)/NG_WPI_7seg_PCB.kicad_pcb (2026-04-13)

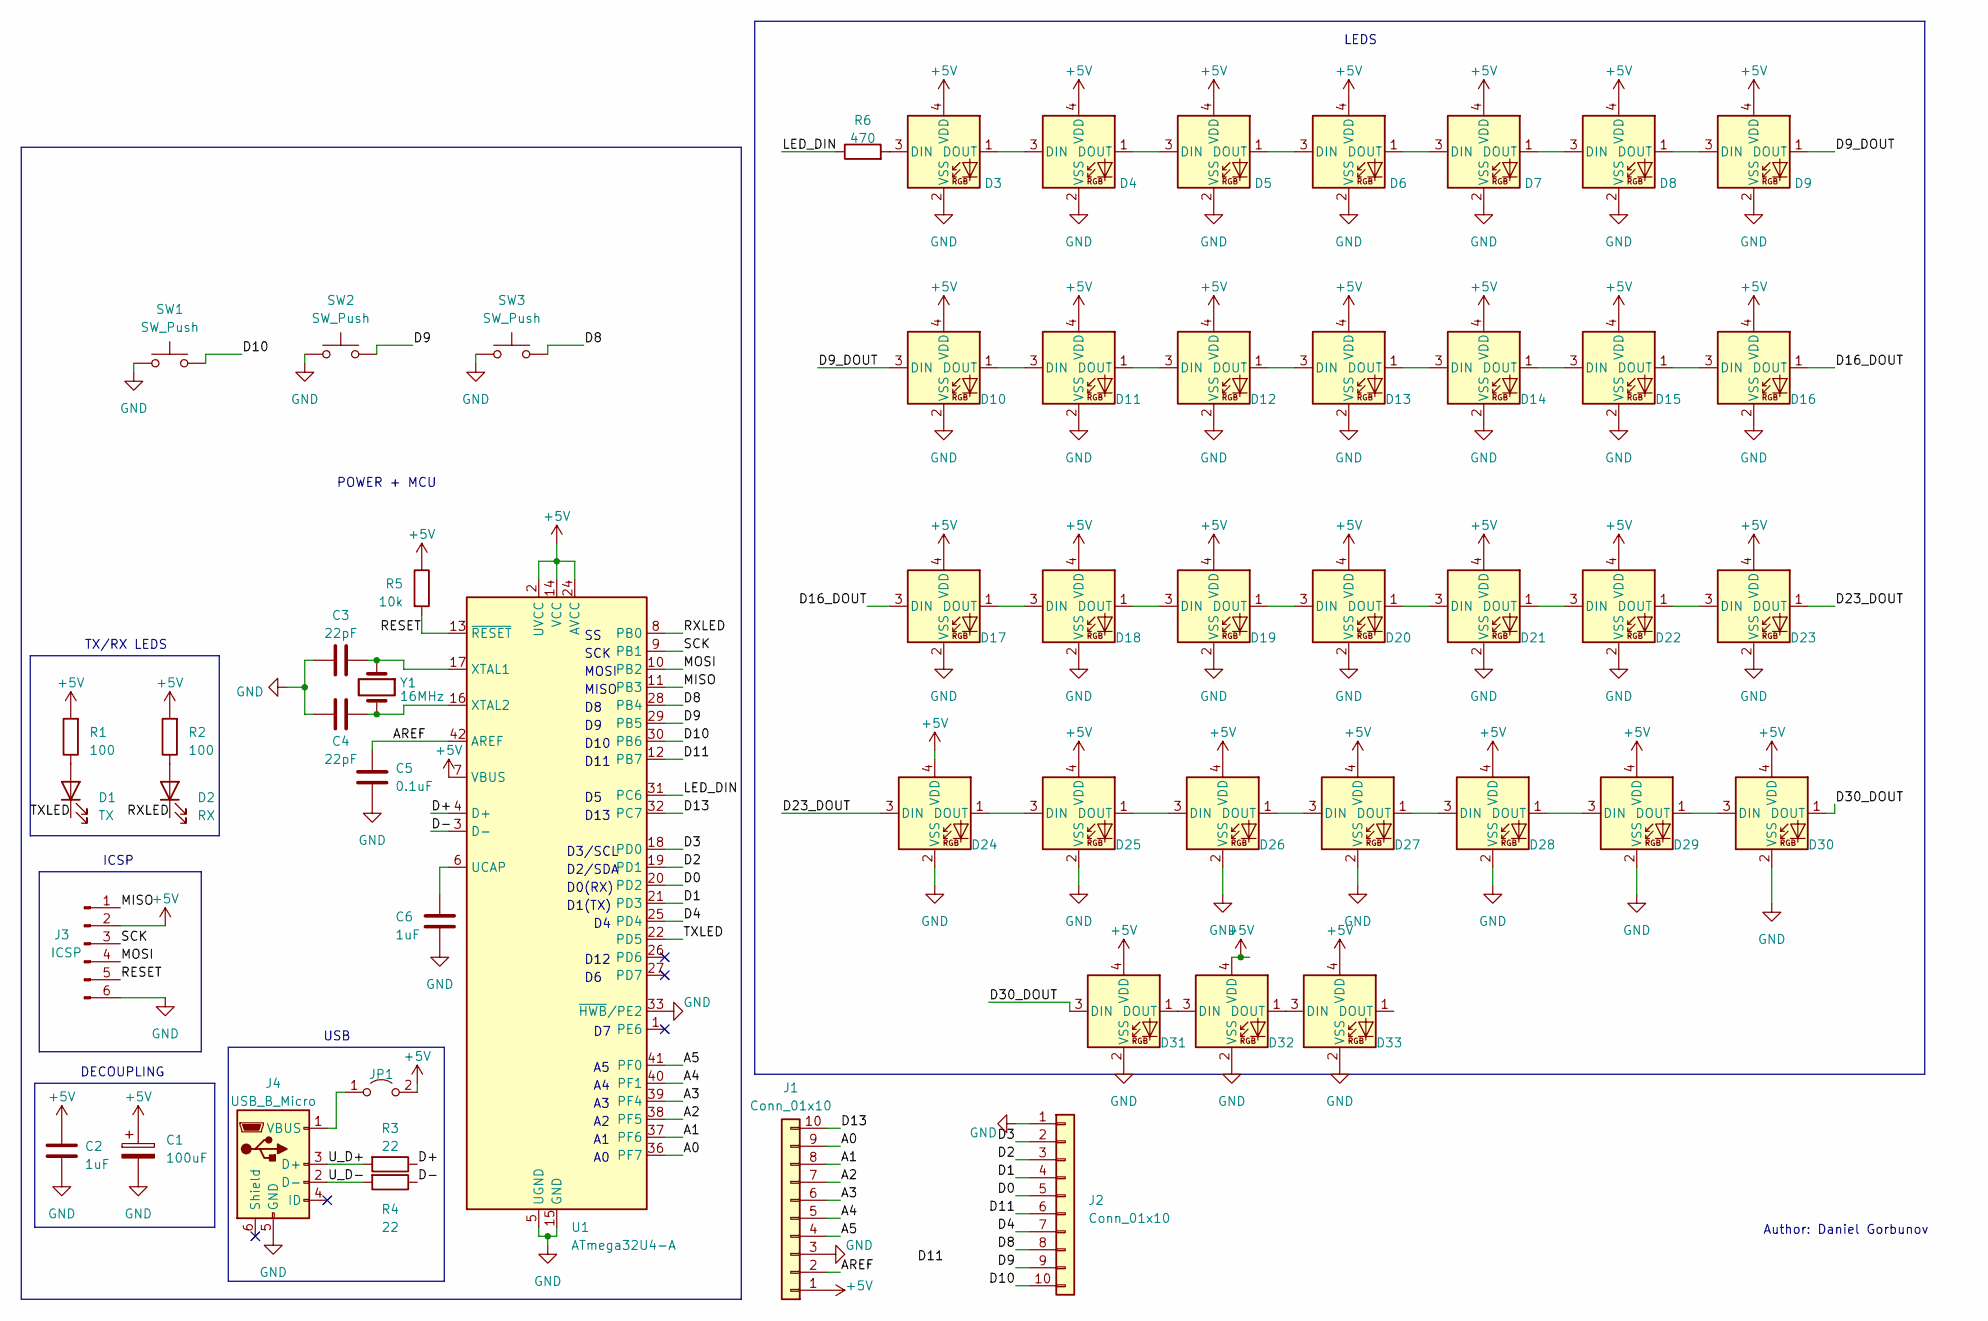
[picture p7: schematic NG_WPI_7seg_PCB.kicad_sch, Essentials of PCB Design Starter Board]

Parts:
C1: 100uF; CP_Elec_5x5.3
C2, C6: 1uF; C_0805_2012Metric_Pad1.18x1.45mm_HandSolder
C3, C4: 22pF; C_0805_2012Metric_Pad1.18x1.45mm_HandSolder
C5: 0.1uF; C_0805_2012Metric_Pad1.18x1.45mm_HandSolder
D1: TX; LED_0805_2012Metric_Pad1.15x1.40mm_HandSolder
D2: RX; LED_0805_2012Metric_Pad1.15x1.40mm_HandSolder
D3, D4, D5, D6, D7, D8, D9, D10, D11, D12, D13, D14, D15, D16, D17, D18, D19, D20, D21, D22, D23, D24, D25, D26, D27, D28, D29, D30, D31, D32, D33: SK6812MINI; LED_SK6812MINI_PLCC4_3.5x3.5mm_P1.75mm
J1, J2: Conn_01x10; PinHeader_1x10_P2.54mm_Vertical
J3: ICSP; PinHeader_2x03_P2.54mm_Vertical
J4: USB_B_Micro; USB_Micro-B_GCT_USB3076-30-A
JP1: Jumper_2_Open; SolderJumper-2_P1.3mm_Open_TrianglePad1.0x1.5mm
R1, R2: 100; R_0805_2012Metric_Pad1.20x1.40mm_HandSolder
R3, R4: 22; R_0805_2012Metric_Pad1.20x1.40mm_HandSolder
R5: 10k; R_0805_2012Metric_Pad1.20x1.40mm_HandSolder
R6: 470; R_0805_2012Metric_Pad1.20x1.40mm_HandSolder
SW1, SW2, SW3: SW_Push; SW_SPST_PTS647_Sx50
U1: ATmega32U4-A; TQFP-44_10x10mm_P0.8mm
Y1: 16MHz; Crystal_SMD_5032-2Pin_5.0x3.2mm

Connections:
+5V: C1.1, C2.1, D3.4 (VDD), D4.4 (VDD), D5.4 (VDD), D6.4 (VDD), D7.4 (VDD), D8.4 (VDD), D9.4 (VDD), D10.4 (VDD), D11.4 (VDD), D12.4 (VDD), D13.4 (VDD), D14.4 (VDD), D15.4 (VDD), D16.4 (VDD), D17.4 (VDD), D18.4 (VDD), D19.4 (VDD), D20.4 (VDD), D21.4 (VDD), D22.4 (VDD), D23.4 (VDD), D24.4 (VDD), D25.4 (VDD), D26.4 (VDD), D27.4 (VDD), D28.4 (VDD), D29.4 (VDD), D30.4 (VDD), D31.4 (VDD), D32.4 (VDD), D33.4 (VDD), J1.1, J3.2, JP1.2 (B), R1.2, R2.2, R5.1, U1.2 (UVCC), U1.7 (VBUS), U1.14 (VCC), U1.24 (AVCC), U1.34 (VCC), U1.44 (AVCC)
/A0: J1.9, U1.36 (PF7)
/A1: J1.8, U1.37 (PF6)
/A2: J1.7, U1.38 (PF5)
/A3: J1.6, U1.39 (PF4)
/A4: J1.5, U1.40 (PF1)
/A5: J1.4, U1.41 (PF0)
/AREF: C5.1, J1.2, U1.42 (AREF)
/D0: J2.5, U1.20 (PD2)
/D1: J2.4, U1.21 (PD3)
/D2: J2.3, U1.19 (PD1)
/D3: J2.2, U1.18 (PD0)
/D4: J2.7, U1.25 (PD4)
/D8: J2.8, SW3.2, U1.28 (PB4)
/D9: J2.9, SW2.2, U1.29 (PB5)
/D9_DOUT: D9.1 (DOUT), D10.3 (DIN)
/D10: J2.10, SW1.2, U1.30 (PB6)
/D11: J2.6, U1.12 (PB7)
/D13: J1.10, U1.32 (PC7)
/D16_DOUT: D16.1 (DOUT), D17.3 (DIN)
/D23_DOUT: D23.1 (DOUT), D24.3 (DIN)
/D30_DOUT: D30.1 (DOUT), D31.3 (DIN)
/D+: R3.1, U1.4 (D+)
/D-: R4.1, U1.3 (D-)
/LED_DIN: R6.1, U1.31 (PC6)
/MISO: J3.1, U1.11 (PB3)
/MOSI: J3.4, U1.10 (PB2)
/RESET: J3.5, R5.2, U1.13 (~RESET)
/RXLED: D2.1 (K), U1.8 (PB0)
/SCK: J3.3, U1.9 (PB1)
/TXLED: D1.1 (K), U1.22 (PD5)
/U_D+: J4.3 (D+), R3.2
/U_D-: J4.2 (D-), R4.2
GND: C1.2, C2.2, C3.2, C4.2, C5.2, C6.2, D3.2 (VSS), D4.2 (VSS), D5.2 (VSS), D6.2 (VSS), D7.2 (VSS), D8.2 (VSS), D9.2 (VSS), D10.2 (VSS), D11.2 (VSS), D12.2 (VSS), D13.2 (VSS), D14.2 (VSS), D15.2 (VSS), D16.2 (VSS), D17.2 (VSS), D18.2 (VSS), D19.2 (VSS), D20.2 (VSS), D21.2 (VSS), D22.2 (VSS), D23.2 (VSS), D24.2 (VSS), D25.2 (VSS), D26.2 (VSS), D27.2 (VSS), D28.2 (VSS), D29.2 (VSS), D30.2 (VSS), D31.2 (VSS), D32.2 (VSS), D33.2 (VSS), J1.3, J2.1, J3.6, J4.5 (GND), SW1.1, SW2.1, SW3.1, U1.5 (UGND), U1.15 (GND), U1.23 (GND), U1.33 (~HWB/PE2), U1.35 (GND), U1.43 (GND)
unnamed: D1.2 (A), R1.1
unnamed: D2.2 (A), R2.1
unnamed: D3.3 (DIN), R6.2
unnamed: D3.1 (DOUT), D4.3 (DIN)
unnamed: D4.1 (DOUT), D5.3 (DIN)
unnamed: D5.1 (DOUT), D6.3 (DIN)
unnamed: D6.1 (DOUT), D7.3 (DIN)
unnamed: D7.1 (DOUT), D8.3 (DIN)
unnamed: D8.1 (DOUT), D9.3 (DIN)
unnamed: D10.1 (DOUT), D11.3 (DIN)
unnamed: D11.1 (DOUT), D12.3 (DIN)
unnamed: D12.1 (DOUT), D13.3 (DIN)
unnamed: D13.1 (DOUT), D14.3 (DIN)
unnamed: D14.1 (DOUT), D15.3 (DIN)
unnamed: D15.1 (DOUT), D16.3 (DIN)
unnamed: D17.1 (DOUT), D18.3 (DIN)
unnamed: D18.1 (DOUT), D19.3 (DIN)
unnamed: D19.1 (DOUT), D20.3 (DIN)
unnamed: D20.1 (DOUT), D21.3 (DIN)
unnamed: D21.1 (DOUT), D22.3 (DIN)
unnamed: D22.1 (DOUT), D23.3 (DIN)
unnamed: D24.1 (DOUT), D25.3 (DIN)
unnamed: D25.1 (DOUT), D26.3 (DIN)
unnamed: D26.1 (DOUT), D27.3 (DIN)
unnamed: D27.1 (DOUT), D28.3 (DIN)
unnamed: D28.1 (DOUT), D29.3 (DIN)
unnamed: D29.1 (DOUT), D30.3 (DIN)
unnamed: D31.1 (DOUT), D32.3 (DIN)
unnamed: D32.1 (DOUT), D33.3 (DIN)
unnamed: J4.1 (VBUS), JP1.1 (A)
unnamed: C6.1, U1.6 (UCAP)
unnamed: C3.1, U1.17 (XTAL1), Y1.1
unnamed: C4.1, U1.16 (XTAL2), Y1.2

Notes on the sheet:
MOSI
D2/SDA
LEDS
D11
D3/SCL
USB
DECOUPLING
D1(TX)
D13
Author: Daniel Gorbunov
MISO
D10
POWER + MCU
TX/RX LEDS
ICSP
SCK
D12
D0(RX)

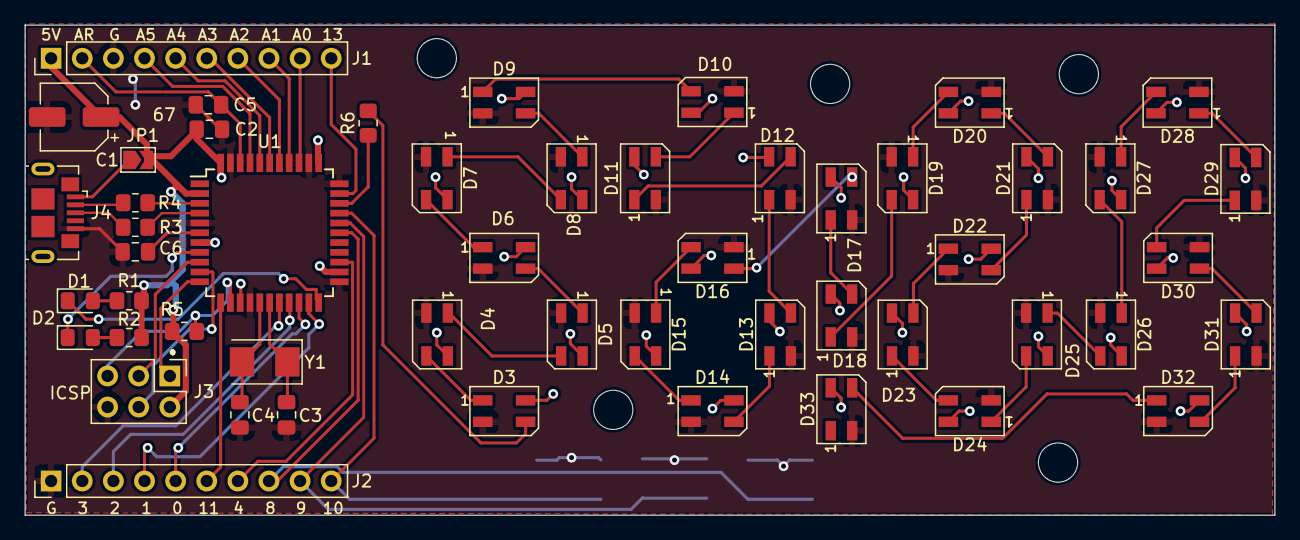
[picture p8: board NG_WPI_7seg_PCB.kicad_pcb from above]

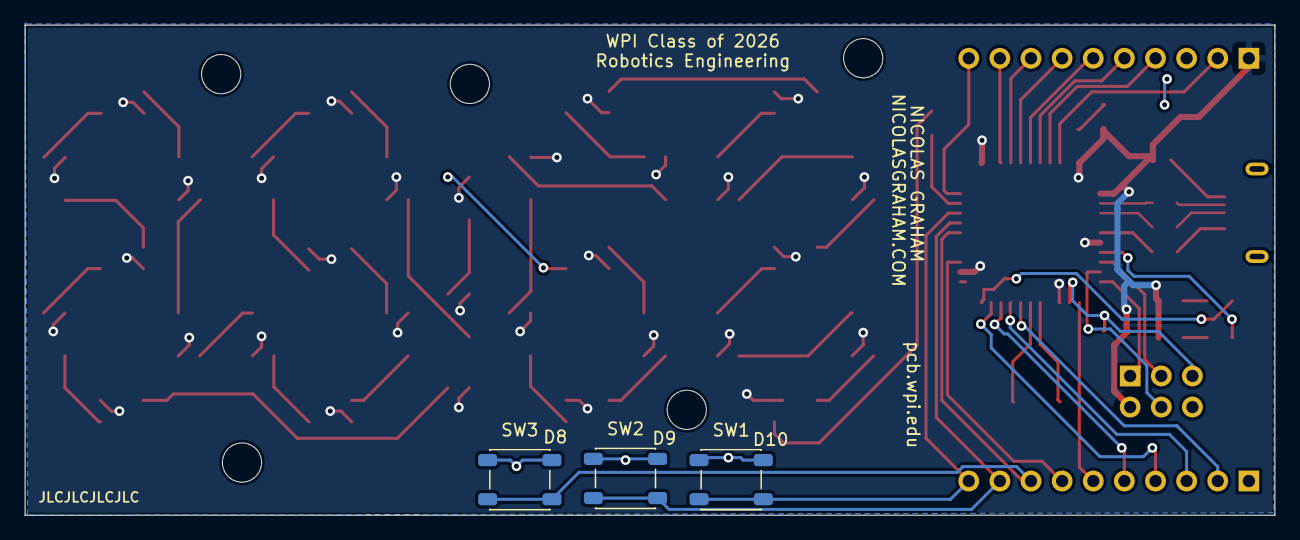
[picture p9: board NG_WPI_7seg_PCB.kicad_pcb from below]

Board: 2 copper layers, 102.0 x 40.0 mm, 55 parts (3 on the bottom side), 67 nets.

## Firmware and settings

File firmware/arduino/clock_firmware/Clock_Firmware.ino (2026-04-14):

#include <Adafruit_NeoPixel.h>
#include <Arduino.h>
#include <RTClib.h>
#include <Wire.h>

#include "src/display/LedMap.h"
#include "src/display/LogicalDisplay.h"
#include "src/hal/Buttons.h"
#include "src/hal/PixelDriver_NeoPixel.h"
#include "src/hal/Rtc_DS3231.h"
#include "src/protocol/ClockRenderProtocol.h"
#include "src/render/SegmentFrameRenderer.h"
#include "src/settings/SettingsStore.h"
#include "src/runtime/RendererRuntime.h"
#include "src/ui/AppStateMachine.h"

namespace Pins {
static constexpr uint8_t kPixels = 5;
static constexpr uint8_t kBtn1 = 8;
static constexpr uint8_t kBtn2 = 9;
static constexpr uint8_t kBtn3 = 10;
}

namespace ProjectInfo {
static constexpr const char* kFirmwareName = "clock_firmware";
static constexpr const char* kFirmwareVersion = "0.4.0";
}

PixelDriver_NeoPixel gPixels(Pins::kPixels, kNumPixels);
LedMap gMap;
LogicalDisplay gDisplay(gPixels, gMap);
Buttons gButtons(Pins::kBtn1, Pins::kBtn2, Pins::kBtn3);
SettingsStore gSettings;
AppStateMachine gApp;
Rtc_DS3231 gRtc;
SegmentFrameRenderer gRenderer(gDisplay, gPixels);
RendererRuntime gRuntime(gButtons, gSettings, gApp, gRenderer);
ClockRenderProtocol gProtocol(Serial, gSettings, gApp, gRtc, gMap, gRuntime, gRenderer,
                              ProjectInfo::kFirmwareName, ProjectInfo::kFirmwareVersion);

static DateTime fallbackNow(uint32_t nowMs) {
  const uint32_t totalSeconds = nowMs / 1000UL;
  const uint8_t seconds = static_cast<uint8_t>(totalSeconds % 60UL);
  const uint8_t minutes = static_cast<uint8_t>((totalSeconds / 60UL) % 60UL);
  const uint8_t hours = static_cast<uint8_t>((totalSeconds / 3600UL) % 24UL);
  return DateTime(2026, 1, 1, hours, minutes, seconds);
}

static DateTime currentNow(uint32_t nowMs) {
  return gRtc.isPresent() ? gRtc.now() : fallbackNow(nowMs);
}

void setup() {
  Serial.begin(115200);
  Wire.begin();

  gPixels.begin();
  gPixels.setBrightness(255);
  gButtons.begin();
  gMap.loadOrDefault();
  gSettings.begin();
  gApp.begin(gSettings.settings(), millis());
  gRuntime.begin(millis());
  gProtocol.begin(224U);

  if (gRtc.begin() && gRtc.lostPower()) {
    gRtc.adjust(DateTime(F(__DATE__), F(__TIME__)));
  }

  gRuntime.requestRender();
  gRuntime.update(millis(), currentNow(millis()));
  gProtocol.sendHello();
}

void loop() {
  const uint32_t nowMs = millis();
  const DateTime now = currentNow(nowMs);

  gProtocol.poll();
  gRuntime.update(nowMs, now);
  gProtocol.flushEvents();
  gSettings.tick(nowMs);
}

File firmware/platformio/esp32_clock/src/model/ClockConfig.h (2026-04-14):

#pragma once

#include <Arduino.h>

#include "../../include/project_config.h"
#include "../display/LogicalIds.h"
#include "../util/Color.h"

enum class ClockMode : uint8_t {
  CLOCK = 0,
  CLOCK_SECONDS,
  TIMER,
  STOPWATCH,
  COLOR_DEMO
};

enum class HourMode : uint8_t { H24 = 0, H12 };
enum class SecondsMode : uint8_t { BLINK = 0, ON, OFF };
enum class TimerDisplayFormat : uint8_t { AUTO = 0, HHMM, MMSS, SSCS };
enum class EffectMode : uint8_t { NONE = 0, RAINBOW, PULSE, PARTY };
enum class WidgetType : uint8_t { PULSE_COLON = 0, RAINBOW_DIGITS, TIMER_WARNING, SECONDS_SPARK, ACCENT_SWEEP };

struct ColorPalette {
  RgbColor digit1;
  RgbColor digit2;
  RgbColor digit3;
  RgbColor digit4;
  RgbColor accent;
  RgbColor seconds;
  RgbColor timerHours;
  RgbColor timerMinutes;
  RgbColor timerSeconds;
  RgbColor stopwatchHours;
  RgbColor stopwatchMinutes;
  RgbColor stopwatchSeconds;
};

// Legacy import compatibility only. The active ESP32 host runtime no longer owns board LEDs,
// buttons, or RTC wiring directly.
struct HardwareSettings {
  uint8_t pixelCount = ProjectConfig::kDefaultPixelCount;
  uint8_t pixelPin = ProjectConfig::kDefaultPixelPin;
  uint8_t buttonPins[3] = {
      ProjectConfig::kDefaultButton1Pin,
      ProjectConfig::kDefaultButton2Pin,
      ProjectConfig::kDefaultButton3Pin,
  };
  uint8_t rtcSda = ProjectConfig::kDefaultRtcSdaPin;
  uint8_t rtcScl = ProjectConfig::kDefaultRtcSclPin;
  String colorOrder = "GRB";
};

struct NetworkSettings {
  String apSsid = "NeoPixelClock";
  String apPassword = "clockclock";
  bool staEnabled = false;
  String staSsid;
  String staPassword;
  String hostname = "neopixel-clock";
};

struct RendererLinkSettings {
  uint32_t baud = ProjectConfig::kDefaultRendererBaud;
  uint8_t txPin = ProjectConfig::kDefaultRendererTxPin;
  uint8_t rxPin = ProjectConfig::kDefaultRendererRxPin;
  bool buttonEvents = true;
};

struct TimeSettings {
  bool ntpEnabled = true;
  String timezone = "EST5EDT,M3.2.0/2,M11.1.0/2";
  String ntpPrimary = "pool.ntp.org";
  String ntpSecondary = "time.nist.gov";
  uint32_t rtcSyncIntervalSeconds = 3600UL;
};

struct RuntimeSettings {
  ClockMode mode = ClockMode::CLOCK;
  HourMode hourMode = HourMode::H24;
  SecondsMode secondsMode = SecondsMode::BLINK;
  TimerDisplayFormat timerFormat = TimerDisplayFormat::AUTO;
  EffectMode effect = EffectMode::NONE;
  uint8_t brightness = 96;
  uint8_t colonBrightness = 160;
  bool rainbowEnabled = false;
  bool calibrationMode = false;
  uint8_t calibrationCursor = 0;
  uint32_t timerPresetSeconds = 300UL;
  String activePresetId = "warm-classic";
  String activeFaceId = "classic-clock";
};

struct PresetDefinition {
  String id;
  String name;
  ColorPalette palette;
  EffectMode effect = EffectMode::NONE;
  bool rainbowClock = false;
};

struct WidgetDefinition {
  String id;
  String name;
  WidgetType type = WidgetType::PULSE_COLON;
  bool enabled = true;
  RgbColor primary = makeRgbColor(255, 255, 255);
  RgbColor secondary = makeRgbColor(0, 120, 255);
  uint16_t thresholdSeconds = 30;
  uint8_t speed = 128;
};

struct FaceDefinition {
  String id;
  String name;
  ClockMode baseMode = ClockMode::CLOCK;
  String presetId;
  EffectMode effect = EffectMode::NONE;
  bool showSeconds = false;
  bool showColon = true;
  bool showDecimal = false;
  bool autoTimerFormat = true;
  String widgetIds[ProjectConfig::kMaxFaceWidgets];
  uint8_t widgetCount = 0;
};

// Legacy import compatibility only. Leonardo calibration remains the authoritative map writer.
struct MappingSettings {
  uint8_t physToLogical[kNumPixels];
};

struct ClockConfig {
  HardwareSettings hardware;
  NetworkSettings network;
  RendererLinkSettings rendererLink;
  TimeSettings time;
  RuntimeSettings runtime;
  MappingSettings mapping;
  PresetDefinition presets[ProjectConfig::kMaxPresets];
  size_t presetCount = 0;
  WidgetDefinition widgets[ProjectConfig::kMaxWidgets];
  size_t widgetCount = 0;
  FaceDefinition faces[ProjectConfig::kMaxFaces];
  size_t faceCount = 0;
};

inline const char* clockModeName(ClockMode mode) {
  switch (mode) {
    case ClockMode::CLOCK: return "CLOCK";
    case ClockMode::CLOCK_SECONDS: return "CLOCK_SECONDS";
    case ClockMode::TIMER: return "TIMER";
    case ClockMode::STOPWATCH: return "STOPWATCH";
    case ClockMode::COLOR_DEMO: return "COLOR_DEMO";
    default: return "CLOCK";
  }
}

inline ClockMode clockModeFromString(const String& value) {
  if (value == "CLOCK_SECONDS") return ClockMode::CLOCK_SECONDS;
  if (value == "TIMER") return ClockMode::TIMER;
  if (value == "STOPWATCH") return ClockMode::STOPWATCH;
  if (value == "COLOR_DEMO") return ClockMode::COLOR_DEMO;
  return ClockMode::CLOCK;
}

inline const char* hourModeName(HourMode mode) {
  return mode == HourMode::H12 ? "12H" : "24H";
}

inline HourMode hourModeFromString(const String& value) {
  return value == "12H" ? HourMode::H12 : HourMode::H24;
}
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

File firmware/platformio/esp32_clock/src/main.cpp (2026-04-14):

#include <Arduino.h>

#include "host/LeonardoClient.h"
#include "runtime/HostRuntime.h"
#include "storage/SettingsStore.h"
#include "web/WebUiServer.h"

SettingsStore gStore;
LeonardoClient gRenderer(Serial2);
HostRuntime gRuntime(gStore, gRenderer);
WebUiServer gWebUi(gStore, gRuntime);

void setup() {
  Serial.begin(115200);
  delay(80);

  gStore.begin();
  gRenderer.begin(gStore.config().rendererLink);

  gRuntime.begin();
  gWebUi.begin();

  Serial.println();
  Serial.println("OK BOOT ClockHost/1");
}

void loop() {
  const uint32_t nowMs = millis();
  gRuntime.update(nowMs);
  gWebUi.update();
}

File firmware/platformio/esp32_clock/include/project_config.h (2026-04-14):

#pragma once

#include <Arduino.h>

namespace ProjectConfig {
static constexpr const char* kFirmwareVersion = "0.2.0";
static constexpr uint8_t kDefaultPixelCount = 31;
static constexpr uint8_t kDefaultPixelPin = 18;
static constexpr uint8_t kDefaultButton1Pin = 25;
static constexpr uint8_t kDefaultButton2Pin = 26;
static constexpr uint8_t kDefaultButton3Pin = 27;
static constexpr uint8_t kDefaultRtcSdaPin = 21;
static constexpr uint8_t kDefaultRtcSclPin = 22;
static constexpr uint8_t kDefaultRendererTxPin = 17;
static constexpr uint8_t kDefaultRendererRxPin = 16;
static constexpr uint32_t kDefaultRendererBaud = 115200UL;
static constexpr uint16_t kRenderRefreshMs = 40;
static constexpr uint32_t kSaveDebounceMs = 1500UL;
static constexpr uint32_t kStatusPollMs = 1000UL;
static constexpr uint32_t kRendererHelloRetryMs = 1500UL;
static constexpr uint32_t kRendererRtcPollMs = 15000UL;
static constexpr uint32_t kRendererMapPollMs = 30000UL;
static constexpr uint32_t kRendererControlRefreshMs = 4000UL;
static constexpr uint32_t kNtpPollMs = 60000UL;
static constexpr size_t kMaxPresets = 12U;
static constexpr size_t kMaxWidgets = 12U;
static constexpr size_t kMaxFaces = 12U;
static constexpr size_t kMaxFaceWidgets = 6U;
}

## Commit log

2026-04-13 Archived WPI pcb starter repo
    [digikey_bom.csv, sample_board.kicad_pcb, sample_board.kicad_sch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]
2026-04-14 v1 ig
    -timer
    - clock
    -stopwatch
    -gui
    everything ig lol
    commiting 67 files to main...
2026-04-14 seperation of calibration tool and customization
2026-04-14 transfer to esp32 overhaul
2026-04-14 Changed for external esp32 dual mcu architechture
    innitial esp32 layout was flayed, assumed bypassing onboard chip,
    in reality this is not practical and needed esp32 to drive and leonardo to render the stuff.

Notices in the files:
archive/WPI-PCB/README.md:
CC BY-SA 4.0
